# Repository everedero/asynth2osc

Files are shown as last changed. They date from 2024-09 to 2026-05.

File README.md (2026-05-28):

# Analog synthesizer to Open Sound Control (OSC) module

## Project description

Analog synth is coming back into hype among music artists. It has a strong culture of vintage, DIY, and customisation.

On the other hand, pro systems use digical control systems, such as DMX for lighting, or OpenSoundControl (OSC) for sound.

The idea for this project is to have a hardware to interface analog synth to advanced sound control systems.

This project is also designed to leverage the possibilities of open-source show control software [Chataigne](https://benjamin.kuperberg.fr/chataigne/).

There are a lot of solution to control an analog modular synthesizer from a computer, mainly by MIDI interfaces.
But not so much options to do the opposite: control others FROM analog modulations.
The features and purpose are very close to existing [Befaco VCMC](https://www.befaco.org/vcmc-2/), but with TCP-IP for OSC instead of serial for MIDI - so we need to change the microcontroller.

Some inspiration for hardware can be found at open hardware synths from Mutable Instruments company.
In its [repository](https://github.com/pichenettes/eurorack) we can find the exact reference design,
typically for the [Yarns V3](https://pichenettes.github.io/mutable-instruments-documentation/modules/yarns/) MIDI digital interface.

## Glossary

### Musical Instrument Digital Interface (MIDI)
Communication protocol dedicated to music, used for communication between musical instruments and multimedia devices.
Usually it is implemented as a serial connection, with a 5-pins DIN connector.

### OpenSoundControl (OSC)
Open, message-based protocol for communication between multimedia devices. Intended to be a next-generation replacement for MIDI.
[OSC specification 1.0 (Stanford University)](https://opensoundcontrol.stanford.edu/spec-1_0.html)
It is usually implemented on TCP-IP stack, most usually as UDP datagrams for real time applications.
It can be easily transmit thru Ethernet or Wifi at higher bit rate, and a much higher resolution of 32 bits float, than MIDI wich was based on 7 bits integer.

### CV - Control Voltages
The analog signals generated by the synthetisers are called CV.

### Gate and triggers
Other types of signals generated can be:
* Gate: a "digital" 0 and 1 signal, but with the synthesiser reference analog voltage,
* Trigger: a short-pulse "digital" 0 and 1 signal, to trigger a particular event.

### Chataigne
Chataigne is a user-friendly open-source show control software, allowing to connect several multimedia devices, hardware or software between them.
We develop belongside this hardware project asynth2osc a custom module for Chataigne, so this piece of software can be use easily to control anything from a real world analog modular,
from sound to light, videos and activators of any kind.

[Chataigne source code on Github](https://github.com/benkuper/Chataigne)
[Artist-friendly Modular Machine for Art and Technology - Chataigne Official website](http://benjamin.kuperberg.fr/chataigne)

### Analog synthetizer
Synthetizer that uses analog circuits and signals to generate sound electronically.
[See the wikipedia page](https://en.wikipedia.org/wiki/Analog_synthesizer)

### Analog modular synthetizer
Modular synthesizers are composed of separate hardware modules for different functions.
The modules can be connected together by the user to create a patch.
The outputs from the modules may include audio signals, analog control voltages, or digital signals for logic or timing conditions.
[See the wikipedia page](https://en.wikipedia.org/wiki/Modular_synthesizer)

### VCV Rack
Open-source software that emulate analog modular synthetizers. Most of hardware modules are present.
Especially, Tramasoft edited a module that is a kind of emulation of our asynth2osc module : cvOSCcv.
This virtual module can be use to use real world analog hardware to control the software.
[VCV Rack cvOSCcv module page](https://library.vcvrack.com/trowaSoft/cvOSCcv)

### Eurorack
Standardized mechanical format for synthetizer, in a modular 3U rack.
It usually fits in a "case" to ease musicians to build their own synthetizer, and have a unique Power Supply Unit and power busses for all the modules.

The dimensions are normalised :
* 3U = 128.5 mm height (U is professionnal standard 19" wide rack unit)
* 1HP = 5.08 mm, width is multiple of 1HP
* Depth should be <2.5mm or <4mm to be shallow

Exemple: Yarns is 12 HP and 3U, so front plate is 128.5x60.96mm. Its bottom PCB is tinier: 59x106,8mm, and has 3 screw holes to fit it to the front plate.

It uses 3.5mm jack for cabling, +/- 12V power supply on a 2x5p header connector, on the right lower corner of the board (facing the bottom).
Red side = -12V. Print a | on the board to indicate side. Don’t forget the protection circuit.

<!--
        +---------+
        |         |
 +12V   |  o   o  |  +12V
        |         |
 GND    |  o   o  |   GND
        |         |
 GND    |  o   o  |   GND
        |         |
 GND    |  o   o  |   GND
        |         |              |
 -12V   |  o   o  |  -12V        |
        |         |              |
        +---------+              |
                                 |
            ----                 |
                                 |
---------------------------------+
-->
Kroki generated Ditaa

## Benchmark
### Befaco VCMC specs (close features, MIDI only)
* Teensy 32 controller
    * NXP MK20DX256VLH7
    * 2x 16-bit ADC
    * 1x 12-bit DAC

* 8 CV muxed on 1 ADC

### Yarns V3 specs (close MCU, MIDI only)
* ST STM32F103CBT6 controller
    * 2x 12-bit ADC (16 channels)
    * 2x DAC
* External DAC DAC8564
    * 1x 16-bit DAC (4 channels)

## First architecture (RPI for Wifi, Bluetooth and cabled Ethernet support)
The first prototype includes:
* 8 analog inputs
* Rotary encoder and screen
* 4 digital inputs and 4 buttons for 8 interrupt inputs
* 1 analog audio output
* Pretty front panel with Eurorack format
* 5V power supply input

The BOM is:
* Raspberry Pi 3
* Pi-Plates DAQC2
* Adafruit I2C rotary encoder module, with click and LED #4991
* Adafruit quad-alphanumeric segmented display with I2C #1912
* 4 mini-arcade buttons with retro-lighting

### Pi-Plates DAQC2
This RPI hat is the GPIO interface, with a very good analog front end:
* Specs [here](https://pi-plates.com/daqc2r1/)

* SoC: Microchip PIC16F1517-I/PT
* 16x 10-bit ADC
* Analog input via TI SN74LV4051A 8:1 analog multiplexer
* Open Collector outputs via TI DS2003CM high-current Darlington driver and NXP 74HC 8-bit parallel-in/serial out shift register.

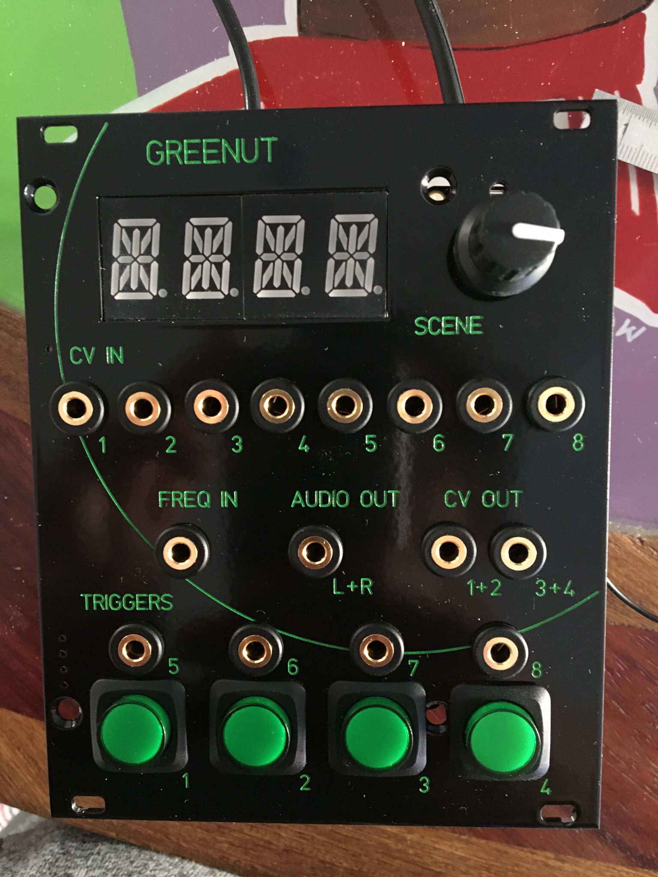
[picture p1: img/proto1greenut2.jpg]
proto1 front panel assembled

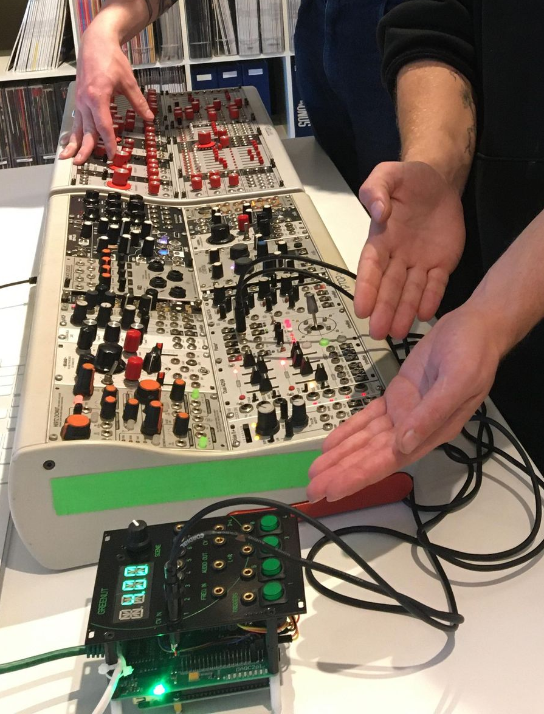
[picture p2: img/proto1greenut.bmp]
proto1 beta tests

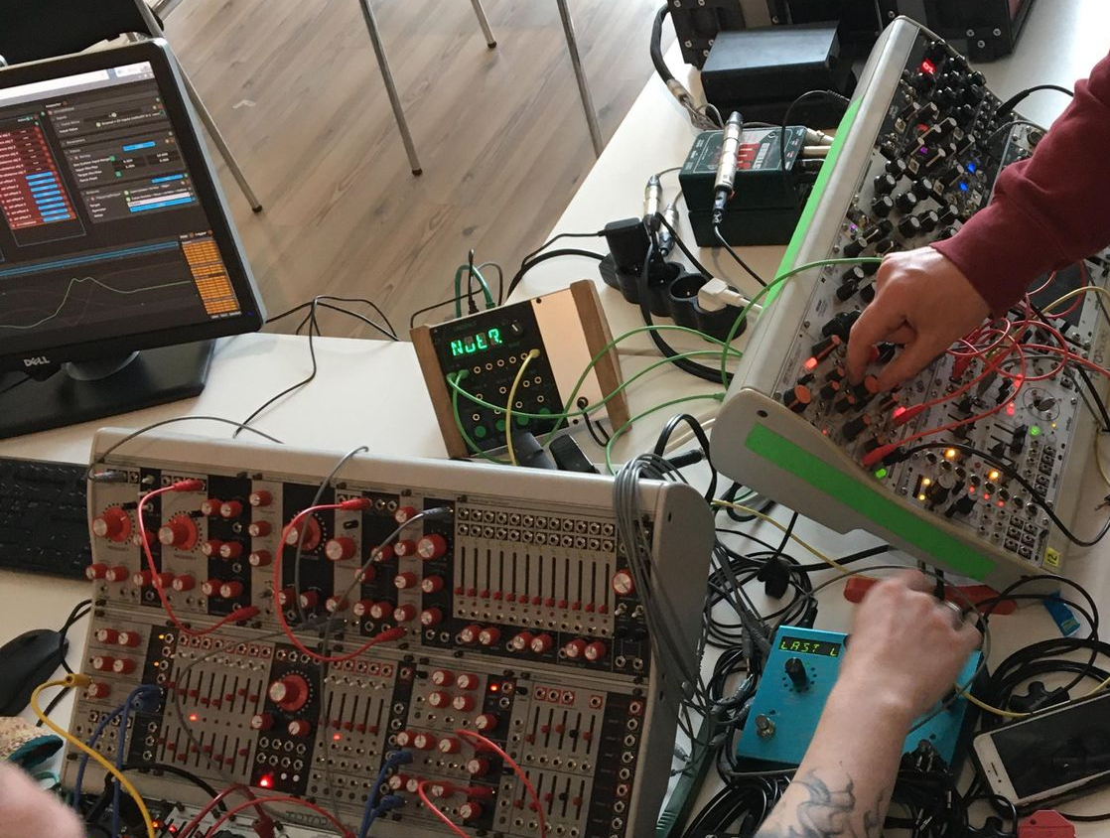
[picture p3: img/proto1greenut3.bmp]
proto1 beta tests


## Second architecture
This aims to integrate LEDs, buttons, and DACs on the same board to improve manufacturing and ralaibilty.
The Raspberry Pi is dropped and replaced by a custom board with WiFi/TCP-IP SoC and all the analog stuff.

It is possible to use a PCB board as front panel too, as a lot of synthesizer modules do.

For the software part, the board would only output the OSC.
I would consider implementing [TinyOSC](https://github.com/mhroth/tinyosc), a lightweight OSC implementation, preferably on Zephyr RTOS.

### Requirements
#### Ethernet
* Full TCP-IP stack implemented, with OSC other UDP protocol.
* DHCP, Link Local and Static IP settings.
* Wired RJ45, optionnal Wifi.

#### DAC
* This has to be the most crucial part for latency. Quick interface is preferable, like SPI.
* 8 channels input (audio stereo 3.5mm mini-jack).
* Minimum 16 bits, preferably 24.
* Sample rate: ideally at least 100Hz, application can be quite slow (LFO are around 2 Hz). Oversamplig is a must for smoothing and lower transmission rate.
* MCP3008 is an option.

#### Other IO
* MIDI input (also using stereo mini-jack).
Even if a lot of MIDI interface exist, and possibilties to send them other Ethernet with rtp-MIDI interfaces and protocol, forwarding some MIDI events to OSC would be a good feature.
With options to set the kind of datas (Programm Changes, Note ON, Control Changes etc) to be tranmitted.

MIDI in uses an UART port, see the [Arduino tutorial](https://www.instructables.com/Send-and-Receive-MIDI-with-Arduino/), or Yarns hardware.
Midi-jack pinout:

<!--
          | |
          +-+
NC 3  o           o  1  NC

Tip 5   o       o  4 Ring

            o
            2 Sleeve

          | |
          +-+
NC 3  o           o  1  NC

OUT- 5  o       o  4 OUT+

            o
            2 GND/Shield
-->
Kroki generated Ditaa

UART baud rate is 31250 kbps.

This is typa A MIDI on TRS, as explain in MIDI Standard : [https://midi.org/specification-for-use-of-trs-connectors-with-midi-devices](https://midi.org/specification-for-use-of-trs-connectors-with-midi-devices)
Warning : There is a type B standard also in use, see [https://minimidi.world/](https://minimidi.world/)

#### Power supply
Eurorack standard includes a +12/-12V power supply, but the currents are quite low, and sensitive to pollution. So we should rather use a 5V additional external power supply as an option.

#### Mechanical
It has to fit in Eurorack format. The smaller, the better,but no hard requirement for width.
Some work has to be done to fit the connectors, leds, buttons and mechanical parts nicely.

#### CV inputs

VC analog inputs can wiggle between several voltage ranges:
* -5V / 5V
* -12V / 12V
* 0 / 5V
* 0 / 12V

We need an input stage able to fit those input the 0 / 3.3V ADC microcontroller input.

Attenuators are specific modules used to reshape a specific CV.

The most used input is copied from Mutable Instruments and remaps a -5V / 5V input in a 0 / 3.3V output, but needs a -10V bias to handle those negatives.
In Befaco VCMC, an optional voltage gizmo converts 5V power supply to -12V / +12V for standalone behaviour.
We could also use an inverting circuit but it will... invert: -5V mapped to 3.3V and 5V mapped to 0V.

Voltages are clamped to 0-3.3V using Shottky diodes, but it should maybe signal saturation to the user somehow.

Better scaling:
* Several input scalers muxed?
* A fancy IC with digital control?
* Single scaler controlled by DAC output (hard)?
* 2-steps converter: rescaler (-12/12 to -5/5), scaler (-5/5 to 0/3).

#### Diagram
<!--
graph TD
  A[ ESP32 ] ==>| RMII | B[ Ethernet PHY ]
  A <==> | SPI | C[ NOR Flash ]
  A <==> | I2C | D[ GPIO expander ]
  T> MIDI in] ==> D
  D ==> | GPIO | E> LEDs ]
  F> Buttons ] ==> | GPIO | D
  G[ ADC ] ==> | SPI | A
  H[ Analog magic ] ==> | Analog | G
  I> 3.5 jacks ] ==> H
  B ==> J> RJ45 ]
  A ==> | DAC | M[ Analog out ]
  M ==> N> 3.5 jack ]
  M ==> O> PWM LED ]
  K> Power jack ] -.- | 12V | L[ DCDC ]
  L -.- | 3V3 | A
  A <==> | UART, JTAG | P[ FTDI ]
  P ==> Q> Debug USB ]
  Q -.- | 5V | L
  A === | U.FL | R[ Antenna ]
  A ==> | SPI | S> Display ]
-->

Kroki generated Mermaid

#### STM32 option
* Only performance range (STM32F7 and STM32H7) have RMII
* STM32H7 has 16-bits ADC, it's perfect

<!--
graph TD
  A[ STM32 ] ==>| RMII | B[ Ethernet PHY ]
  A <==> | SPI | C[ NOR Flash ]
  A <==> | GPIO | D> LEDs ]
  E> Buttons ] ==> | GPIO | A
  H[ Analog in ] ==> | ADC | A
  I> 3.5 jacks ] ==> H
  B ==> J> RJ45 ]
  A ==> | DAC | F[ Analog out ]
  F ==> N> 3.5 jack ]
  A ==> | PWM | O> PWM LED ]
  K> Power jack ] -.- | 12V | L[ DCDC ]
  L -.- | 3V3 | A
  A <==> | UART, JTAG | P> SWD header ]
  L -.- | 5V | G
  A ==> | SPI | S> Display ]
  T> 3.5 jack ] ==> U[ MIDI In ]
  U ==> | GPIO | A
  A <==> | USB | G> Debug USB ]
-->
Kroki generated Mermaid

# Power consumptions estimates
## 3V3 bus
* STM32H7 absolute maximum current through VDD/VSS: 620mA
* STM32H7 running at 100deg, VOS1, all peripheral enabled: around 500mA
* ETH PHY, 10BASE-T traffic: 130mA
* OLED display logic: 300uA

* 3V3 LDO: 800 mA
* Fuse: 1.25A, trip 2.5A
* Filter ferrite rating: 3A
* Schottky rating (SS24): 2A

## 10V
* OLED display lighting: 25mA
* Step-up rating: 2.1A
* Step-up inductor: 2.4A
* Schottky rating (SS24): 2A

## 12V
* Schottky rating (1N5819W): 1A
* LDO efficiency (vout/vin): 12-5V -> 42%, 5-3V -> 66%
* 800mA @ 3V3 => 800mA @ 12V (not crazy, but linear)

## 5V
* USB spec: 500 mA in USB 2.0
* USB spec: 900 mA in USB 3.0
* USB 2.0: 500mA on 3V3 after LDO
* USB 3.0: 900mA on 3V3 after LDO
Might be useful to have USB 3.0 supply.

# Notes about JLCPCB files
## Generate files

Some modification are required from Kicad output files (BOM csv and placement files) to be imported to JLCPCB for assembly.

* Change field names in BOM and placement CSV headers
* Fix component rotation

There is a way to automate both with a Python script called [jlc-kicad-tools](https://github.com/matthewlai/JLCKicadTools/tree/master).

This script uses a rotation look-up-table called cpl\_rotations\_db.csv. Update this file with the one in this repository.

    cp [PRJ]/kicad/tools/cpl_rotations_db.csv [INSTALLFOLDER]/JLCKicadTools/jlc_kicad_tools

Then install your version from the local folder:

    pip3 install [INSTALLFOLDER]/JLCKicadTools

You will need 2 files in the project folder:

* Netlist file: project.xml
* Placement file: project-all-pos.csv

In order to get the project.xml file, in Eeschema, go to "Legacy BOM", create a custom XML exporter with the following command:
```
/bin/echo "%I"
```

Don’t forget to create a "JLCPCB" column with the JLCPCB references, for advanced components. For standard ones, keep their value and package and use the "--include-all-component-groups", otherwise the script will erase them.

Exemple use:
```
jlc-kicad-tools myproject -o ./assembly --include-all-component-groups
```

## Pricing

Here is an approximate price breakdown for manufacturing at JLCPCB.
Some components, such as though-hole or big components, will be ordered separately on LCSC and soldered by hand.
The "component" line includes both PCBa and by-hand BOMs.
Here, we manufacture 5 boards.

| Item | Price |
|---|---|
| Components | 151€  |
| PCB manufacturing | 28€ |
| PCB assembly | 105€  |
| Shipping | 35€ |
| Refunds | 18€ |
| Total (x5 boards) | 300€  |

This is a total of 60€ / board.

# Bringup
## V0.1 known issues
* PHY: Error in LDO routing: VDDCR pin 6 is an internally regulated LDO 1.2V output, not to be connected to 3V3 supply.
Add 1 μF and 470 pF decoupling capacitors to ground.
* PHY: nINTSEL should be 0, change LED2 connection to pull-down.
    * REF_CLK_OUT is used to generate the 50MHz clock for RMII
    * This special feature allows to use a 25 MHz crystal with the LAN8742
    * As a consequence, the INT/CLKO pin must be set to clock out, not int
    * This means nINTSEL/LED2 pulled down
* Cannot setup different interrupts for GPIO (EXTI register) having the same numbers but on different ports.
    * See [this issue](https://github.com/zephyrproject-rtos/zephyr/issues/45234).
    * Issue with A8 rotative encoder pushbutton VS C8 rotary input B
    * Issue with D14 rotary input A and E14 trig input
* Shield REFCLK0: it is a 50MHz line!
* Missing pin 1 dot on diode D2 for manufacturing
* Dot around ethernet PHY: crystal dot too close
* Put poka-yoke or marking to mount USB connector on right side
* Put poka-yoke or marking for buttons
* Reduce jack connectors holes to mount more precisely
* Add testpoints for MDIO?
* Maybe disconnect PHY reset from main reset
Reset is pulled low by STLink probe, it has 1V2 value when probe is connected even if not plugged in.

## Bringup todo list
* Debug LEDs: OK
* Buttons: OK
* Buttons LEDs: OK, make markings for equipment
* UART2: OK
* Enable 10V: OK
* USB data: OK, make markings for equipment
* QSPI flash: OK
* MDIO bus / RMII / Ethernet: OK after rework, ldo disconnect and led2 pull-down
* Display: OK, verify grey lines, maybe voltage bias issue
* DAC: TBD
* Analog: OK, CVin ripple at +max value (+5V or +12V)
* Trigger: OK, 1.95ms rise time (max 500 Hz trig)
* MIDI optocoupler: OK at 32kHz, bit of an hysteresis at play. Collapses after 150kHz.
* MIDI: OK, tested with Roland HP201 keyboard output
* Supply (12V alternative input, current consumption measurements): TBD
  * 12V input: 5V LDO works, 214mA consumption with ADC app running, no display
  * 5V input: 208mA consumption with ADC app running, no display
  * 5V filtered output is around 4.5V

## Meca panel known issues
* First CNC run:
  * Rotary hole exact diameter, add a small margin
  * Button hole too small, about 1mm missing, add margin too
  * Jack holes too wide, wiggling
  * Display TBD, might be too small or not

* Reverse-mount LED options:
  * XZDGK45WT-9 (Green)
  * XZCWD45S-9 (White)
  * XZFBB45S-9 (Blue)
  * XZMDK45WT-9 (Red)

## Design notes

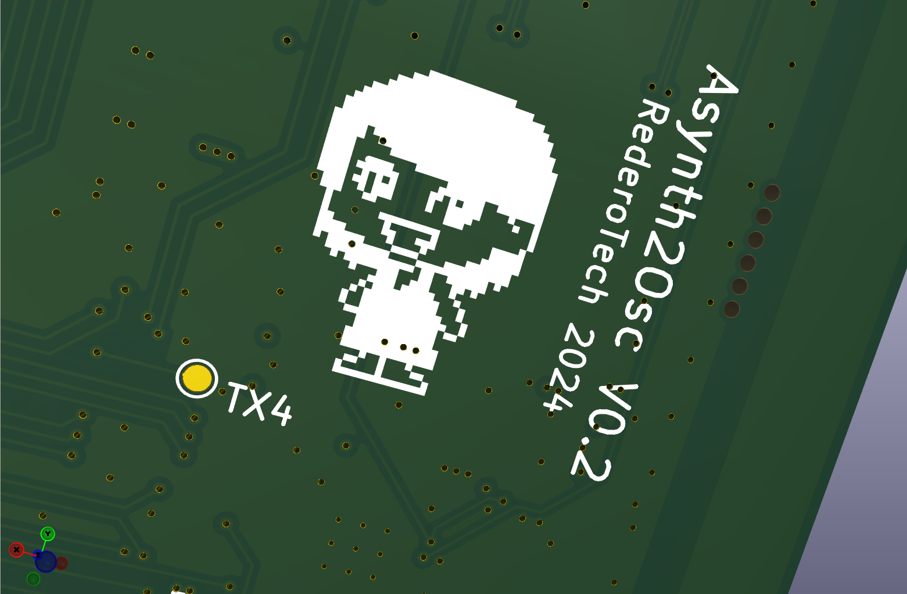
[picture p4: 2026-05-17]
docs/images/RederoTech2024.png

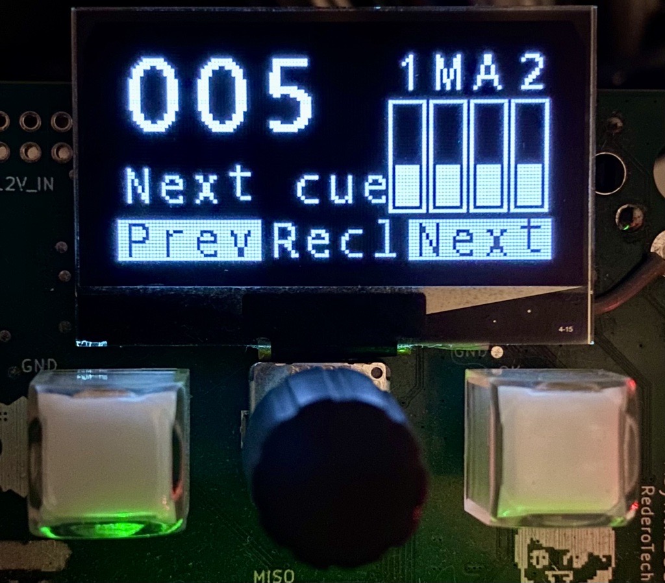
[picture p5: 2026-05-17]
docs/images/oled_ASynthOSC.jpg

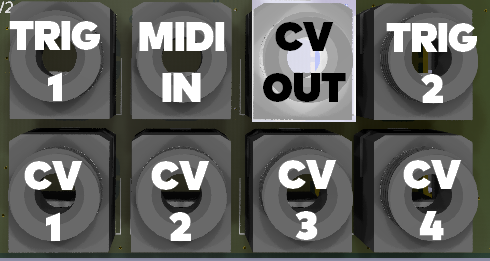
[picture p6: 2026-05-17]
docs/images/jacks_ASynthOSC.png

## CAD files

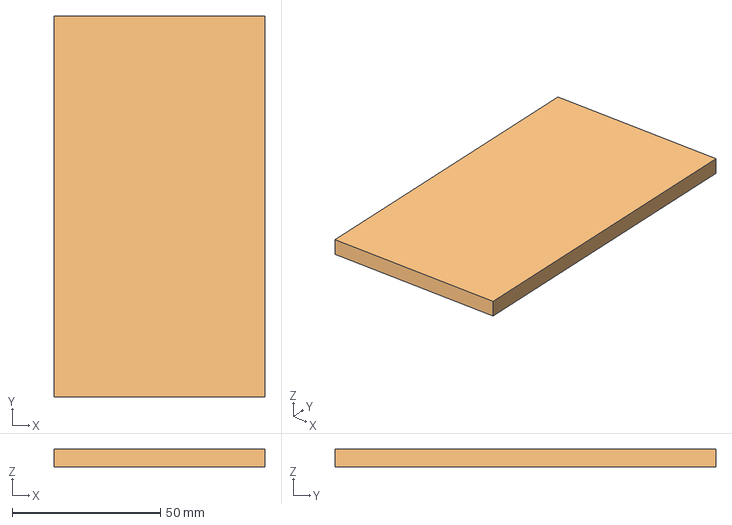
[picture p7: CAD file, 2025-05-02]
freecad/panel_sketch.FCStd
71.1 x 128.4 x 6.00 mm
Model-Body
Stock

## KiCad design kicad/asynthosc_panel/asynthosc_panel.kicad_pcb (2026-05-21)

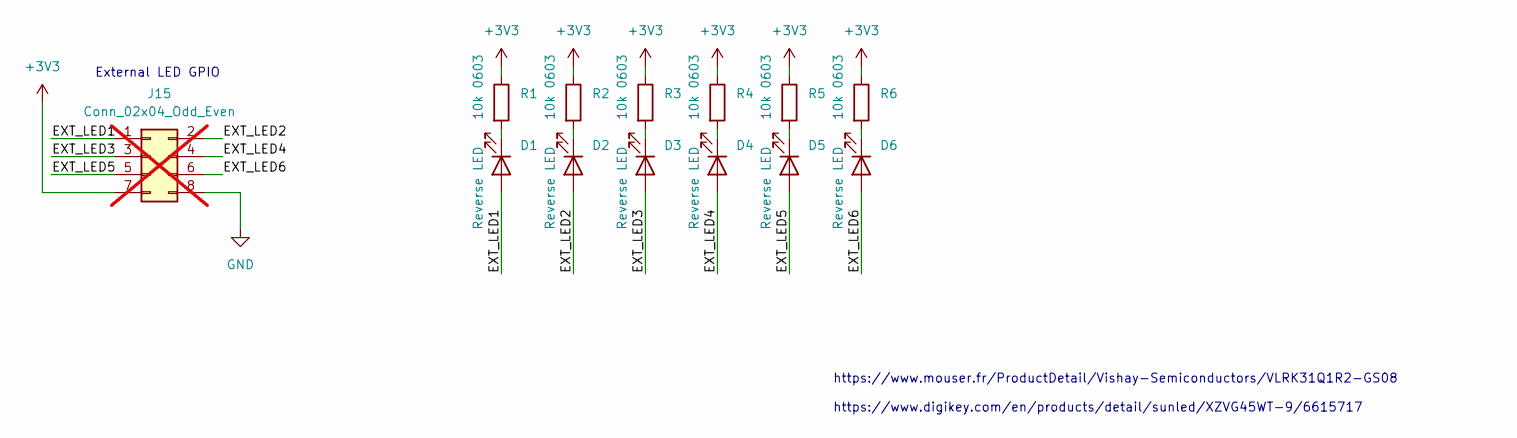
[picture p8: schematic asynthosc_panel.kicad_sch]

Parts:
D1, D2, D3, D4, D5, D6: Reverse LED; LED_Sunled_XZxx45x-9_nohole
J15: Conn_02x04_Odd_Even; PinHeader_2x04_P2.54mm_Vertical_SMD; LCSC C192300; not fitted
R1, R2, R3, R4, R5, R6: 10k 0603; R_0603_1608Metric_Pad0.98x0.95mm_HandSolder

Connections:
+3V3: J15.7, R1.1, R2.1, R3.1, R4.1, R5.1, R6.1
/EXT_LED1: D1.2 (A), J15.1
/EXT_LED2: D2.2 (A), J15.2
/EXT_LED3: D3.2 (A), J15.3
/EXT_LED4: D4.2 (A), J15.4
/EXT_LED5: D5.2 (A), J15.5
/EXT_LED6: D6.2 (A), J15.6
GND: J15.8
unnamed: D1.1 (K), R1.2
unnamed: D2.1 (K), R2.2
unnamed: D3.1 (K), R3.2
unnamed: D4.1 (K), R4.2
unnamed: D5.1 (K), R5.2
unnamed: D6.1 (K), R6.2

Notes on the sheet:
https://www.mouser.fr/ProductDetail/Vishay-Semiconductors/VLRK31Q1R2-GS08 https://www.digikey.com/en/products/detail/sunled/XZVG45WT-9/6615717
External LED GPIO

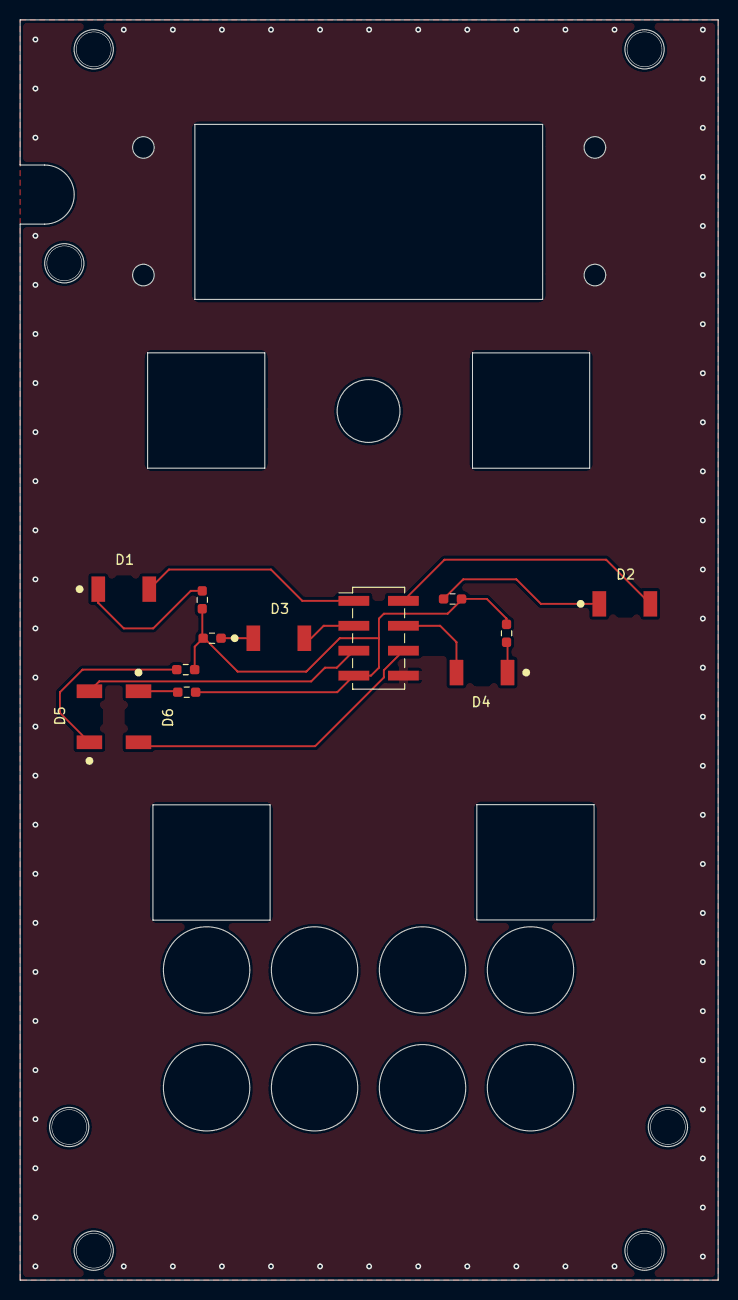
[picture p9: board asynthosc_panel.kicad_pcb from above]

Board: 2 copper layers, 71.1 x 128.4 mm, 13 parts (0 on the bottom side), 13 nets.

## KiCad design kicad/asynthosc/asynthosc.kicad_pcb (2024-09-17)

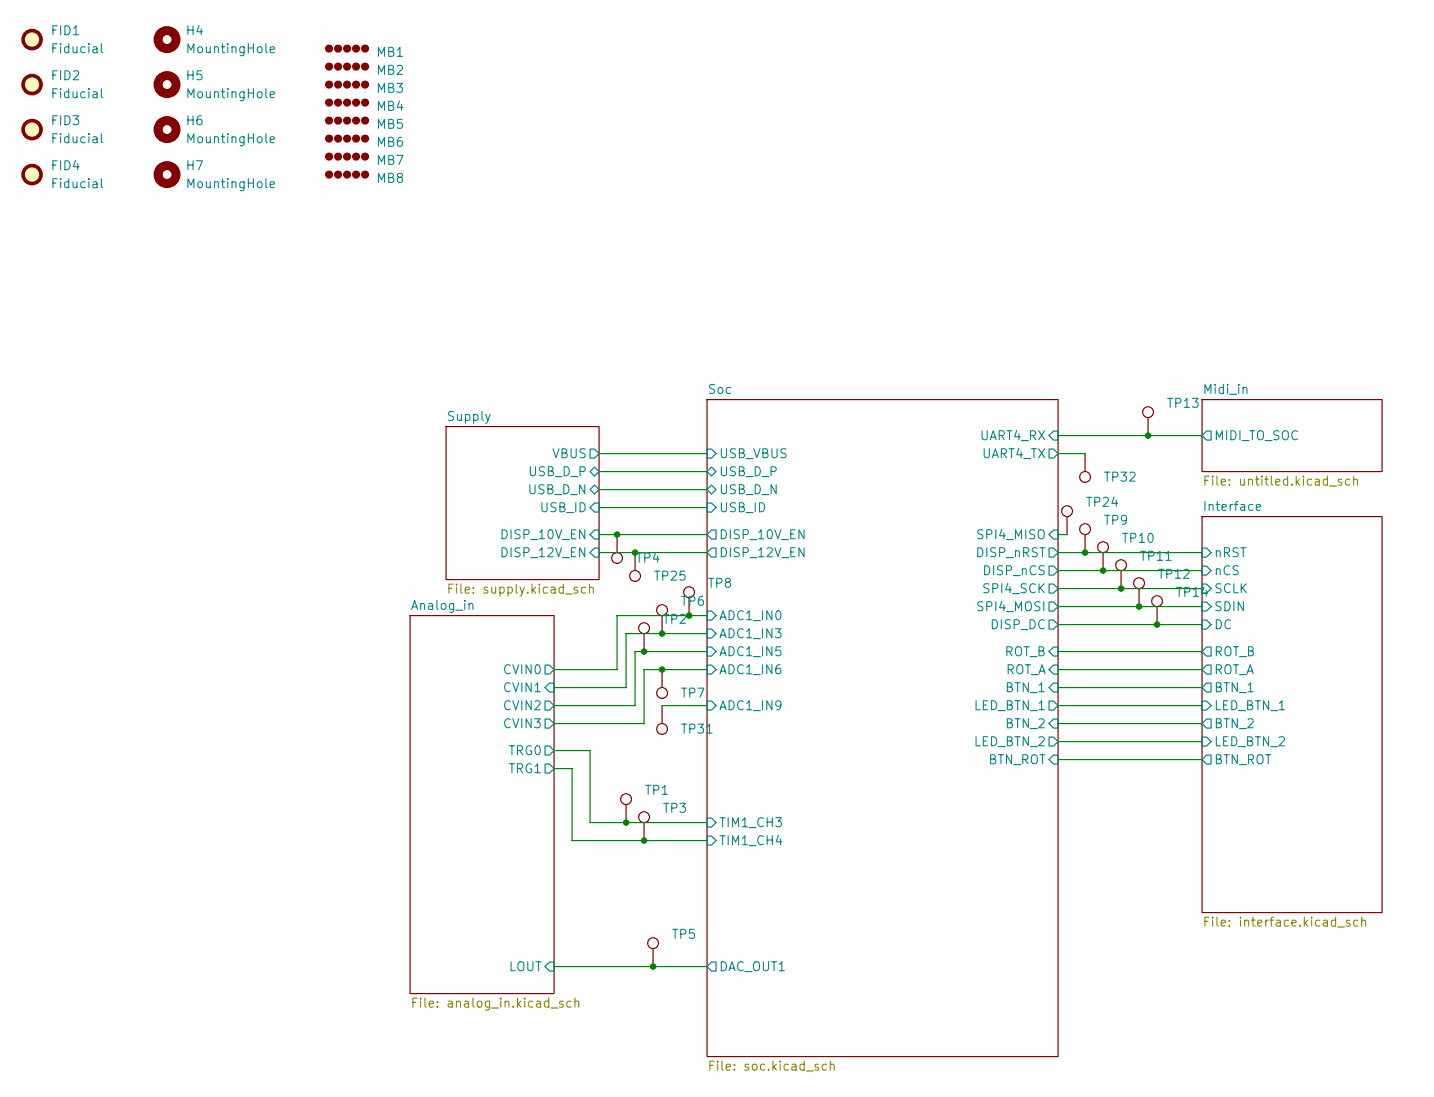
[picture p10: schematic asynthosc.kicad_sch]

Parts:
FID1, FID2, FID3, FID4: Fiducial; Fiducial_1mm_Mask2mm
H4, H5, H6, H7: MountingHole; MountingHole_JLC_3.5mm
MB1, MB2, MB3, MB4, MB5, MB6, MB7, MB8: MouseBytes; MouseBytes_JLC
TP1, TP2, TP3, TP4, TP5, TP6, TP7, TP8, TP9, TP10, TP11, TP12, TP13, TP14, TP24, TP25, TP31, TP32: TestPoint; TestPoint_Pad_D1.0mm

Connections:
/Analog_in/CVIN0: TP8.1; also elsewhere on the board
/Analog_in/CVIN1: TP6.1; also elsewhere on the board
/Analog_in/CVIN2: TP2.1; also elsewhere on the board
/Analog_in/CVIN3: TP7.1; also elsewhere on the board
/Analog_in/TRG0: TP1.1; also elsewhere on the board
/Analog_in/TRG1: TP3.1; also elsewhere on the board
/Interface/DC: TP14.1; also elsewhere on the board
/Interface/SDIN: TP12.1; also elsewhere on the board
/Interface/nCS: TP10.1; also elsewhere on the board
/Interface/nRST: TP9.1; also elsewhere on the board
/Midi_in/MIDI_TO_SOC: TP13.1; also elsewhere on the board
/Soc/ADC1_IN9: TP31.1; also elsewhere on the board
/Soc/DAC_OUT1: TP5.1; also elsewhere on the board
/Soc/DISP_10V_EN: TP4.1; also elsewhere on the board
/Soc/DISP_12V_EN: TP25.1; also elsewhere on the board
/Soc/SPI4_MISO: TP24.1; also elsewhere on the board
/Soc/SPI4_SCK: TP11.1; also elsewhere on the board
/Soc/UART4_TX: TP32.1; also elsewhere on the board

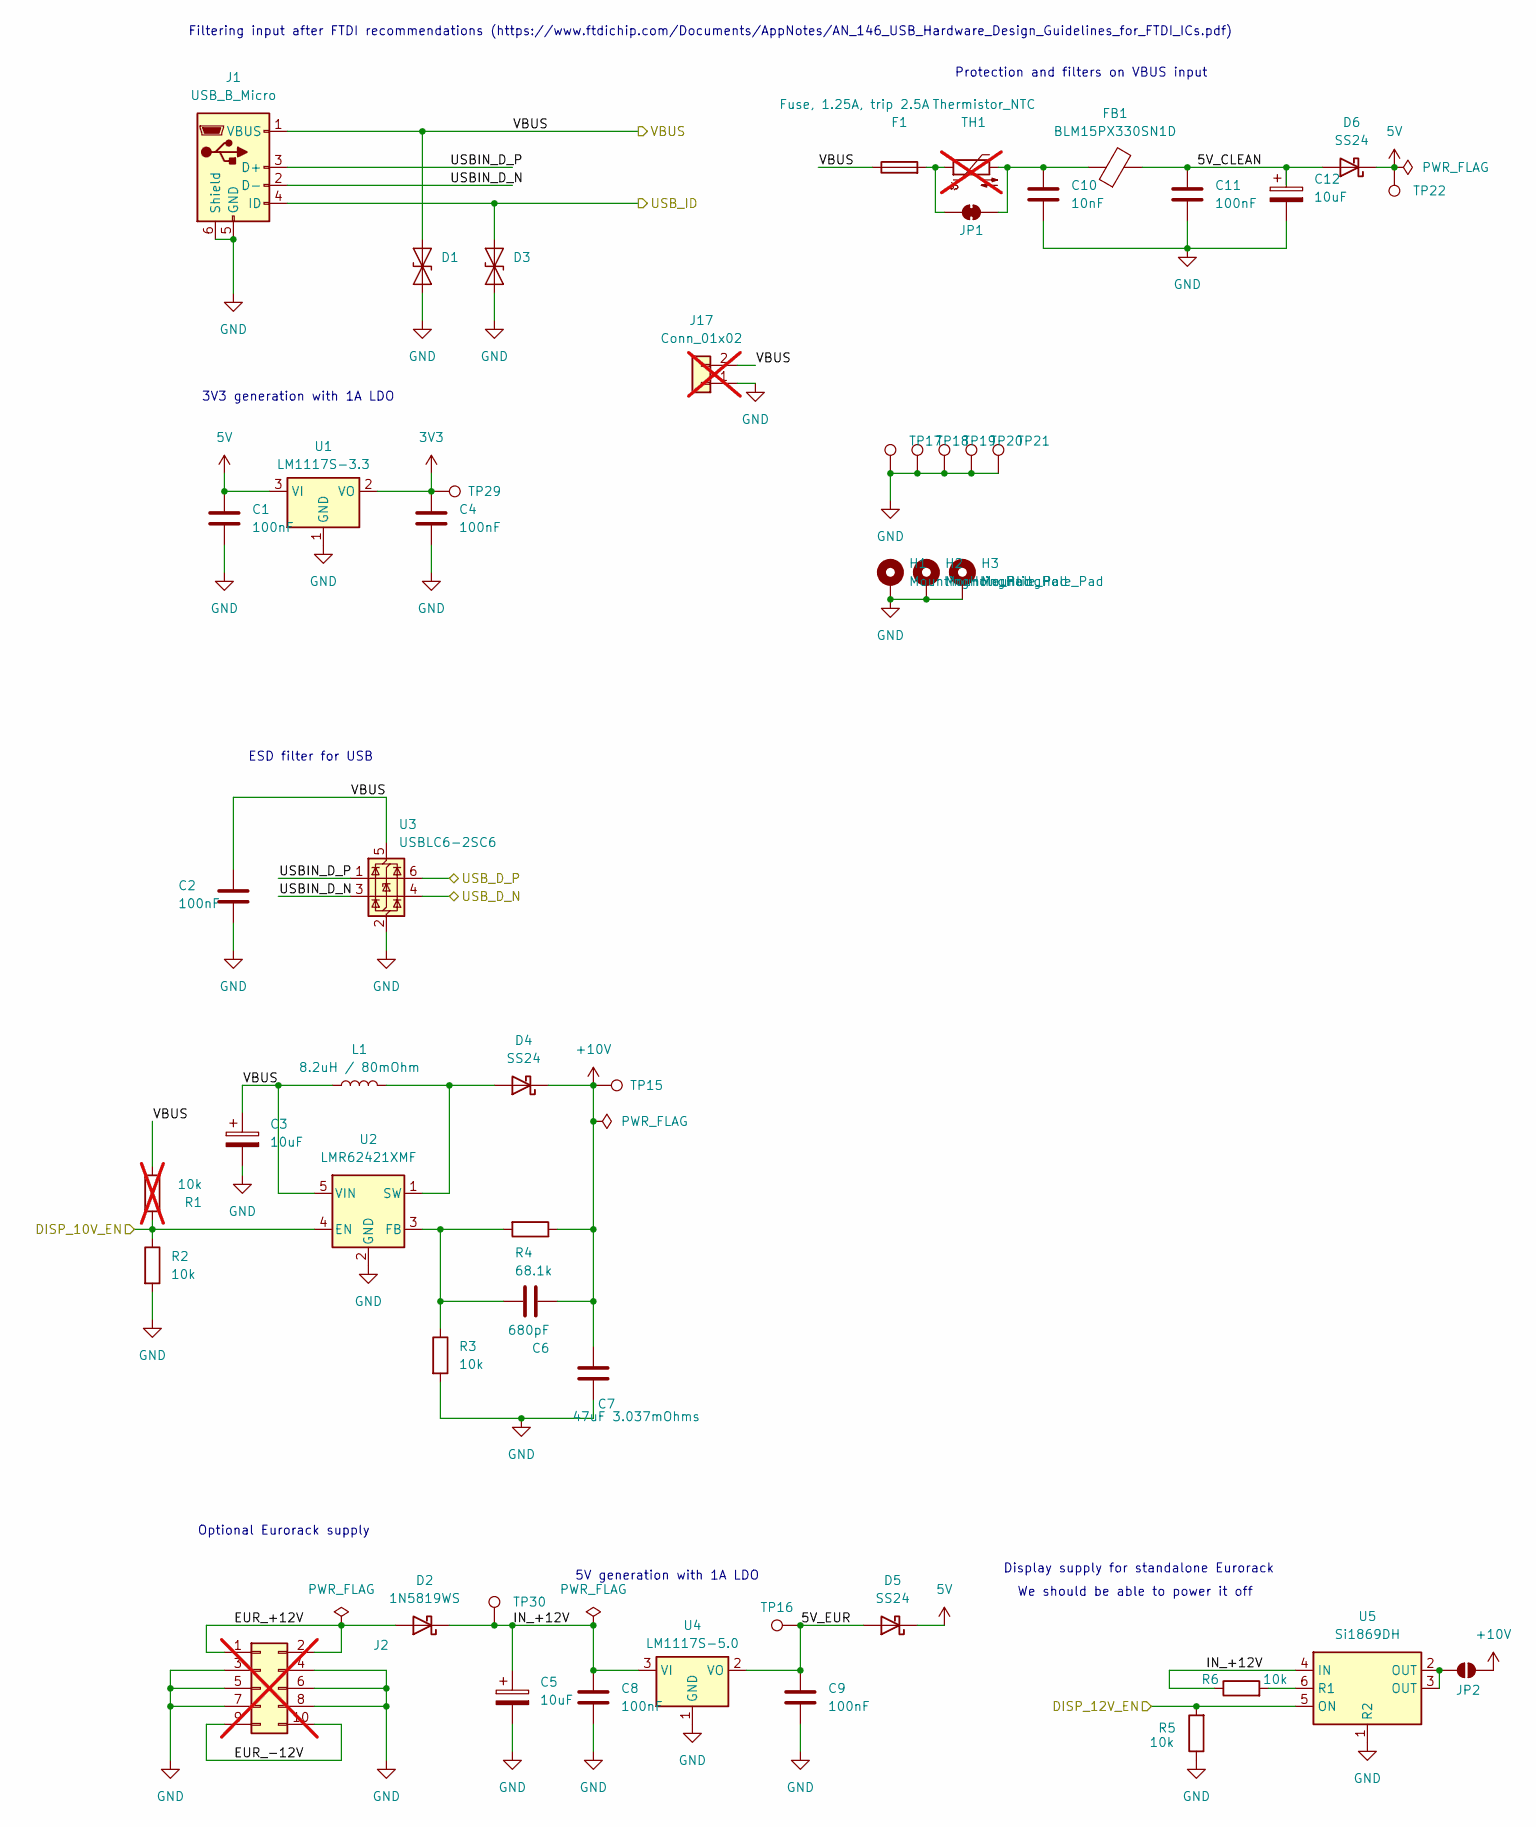
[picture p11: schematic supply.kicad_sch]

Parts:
C1, C2, C4, C8, C9: 100nF; C_0805_2012Metric; JLC 0805
C3, C5, C12: 10uF; CP_Elec_4x5.4; LCSC C72485
C6: 680pF; C_0402_1005Metric; JLC 0402
C7: 47uF 3.037mOhms; C_0805_2012Metric; JLC 0805
C10: 10nF; C_0402_1005Metric; JLC 0402
C11: 100nF; C_0402_1005Metric; JLC 0402
D1, D3: ESD9B5.0ST5G; D_SOD-923; LCSC C111566
D2: 1N5819WS; D_SOD-323; LCSC C2921026
D4, D5, D6: SS24; D_SMA; LCSC C3014007
F1: Fuse, 1.25A, trip 2.5A; R_0805_2012Metric; JLC 0805
FB1: BLM15PX330SN1D; L_0402_1005Metric; LCSC C160974
H1, H2, H3: MountingHole_Pad; MountingHole_2.2mm_M2_Pad
J1: USB_B_Micro; USB_Micro-B_Hanxia_HX_MICRO_180D_ZB; LCSC C5160321
J2: Conn_02x05_Odd_Even; PinHeader_2x05_P2.54mm_Vertical; LCSC C3294463; not fitted
J17: Conn_01x02; PinHeader_1x02_P2.54mm_Vertical; not fitted
JP1: SolderJumper_2_Bridged; SolderJumper_0402_1005Metric_Bridged
JP2: SolderJumper_2_Open; R_0402_1005Metric
L1: 8.2uH / 80mOhm; L_XR_XRCD75-XRX_7x7.8; LCSC C7462918
R1: 10k; R_0402_1005Metric; JLC 0402; not fitted
R2, R3, R5, R6: 10k; R_0402_1005Metric; JLC 0402
R4: 68.1k; R_0402_1005Metric; JLC 0402
TH1: Thermistor_NTC; R_Axial_DIN0204_L3.6mm_D1.6mm_P7.62mm_Horizontal; LCSC C2935581; not fitted
TP15, TP16, TP17, TP18, TP19, TP20, TP21, TP22, TP29, TP30: TestPoint; TestPoint_Pad_D1.0mm
U1: LM1117S-3.3; SOT-223; LCSC C126027
U2: LMR62421XMF; SOT-23-5; LCSC C2070685
U3: USBLC6-2SC6; SOT-23-6; LCSC C7519
U4: LM1117S-5.0; SOT-223; LCSC C126028
U5: Si1869DH; SOT-363_SC-70-6; LCSC C5246384

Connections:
3V3: C4.1, TP29.1, U1.2 (VO); also elsewhere on the board
5V: C1.1, D5.1 (K), D6.1 (K), TP22.1, U1.3 (VI); also elsewhere on the board
+10V: C6.2, C7.1, D4.1 (K), JP2.2 (B), R4.1, TP15.1; also elsewhere on the board
/Soc/DISP_10V_EN: R1.1, R2.1, U2.4 (EN); also elsewhere on the board
/Soc/DISP_12V_EN: R5.2, U5.5 (ON); also elsewhere on the board
/Soc/USB_D_N: U3.4 (I/O2); also elsewhere on the board
/Soc/USB_D_P: U3.6 (I/O1); also elsewhere on the board
/Soc/USB_ID: D3.2 (A2), J1.4 (ID); also elsewhere on the board
/Supply/5V_CLEAN: C11.1, C12.1, D6.2 (A), FB1.2
/Supply/5V_EUR: C9.1, D5.2 (A), TP16.1, U4.2 (VO)
/Supply/EUR_+12V: D2.2 (A), J2.1, J2.2
/Supply/EUR_-12V: J2.9, J2.10
/Supply/IN_+12V: C5.1, C8.1, D2.1 (K), R6.1, TP30.1, U4.3 (VI), U5.4 (IN)
/Supply/USBIN_D_N: J1.2 (D-), U3.3 (I/O2)
/Supply/USBIN_D_P: J1.3 (D+), U3.1 (I/O1)
/Supply/VBUS: C2.1, C3.1, D1.2 (A2), F1.1, J1.1 (VBUS), J17.2, L1.1, R1.2, U2.5 (VIN), U3.5 (VBUS); also elsewhere on the board
GND: C1.2, C2.2, C3.2, C4.2, C5.2, C7.2, C8.2, C9.2, C10.2, C11.2, C12.2, D1.1 (A1), D3.1 (A1), H1.1, H2.1, H3.1, J1.5 (GND), J1.6 (Shield), J2.3, J2.4, J2.5, J2.6, J2.7, J2.8, J17.1, R2.2, R3.2, R5.1, TP17.1, TP18.1, TP19.1, TP20.1, TP21.1, U1.1 (GND), U2.2 (GND), U3.2 (GND), U4.1 (GND), U5.1 (R2); also elsewhere on the board
unnamed: D4.2 (A), L1.2, U2.1 (SW)
unnamed: F1.2, JP1.1 (A), TH1.1
unnamed: C10.1, FB1.1, JP1.2 (B), TH1.2
unnamed: JP2.1 (A), U5.2 (OUT), U5.3 (OUT)
unnamed: C6.1, R3.1, R4.2, U2.3 (FB)
unnamed: R6.2, U5.6 (R1)

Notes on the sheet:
We should be able to power it off
Optional Eurorack supply
Filtering input after FTDI recommendations (https://www.ftdichip.com/Documents/AppNotes/AN_146_USB_Hardware_Design_Guidelines_for_FTDI_ICs.pdf)
Display supply for standalone Eurorack
ESD filter for USB
Protection and filters on VBUS input
5V generation with 1A LDO
3V3 generation with 1A LDO

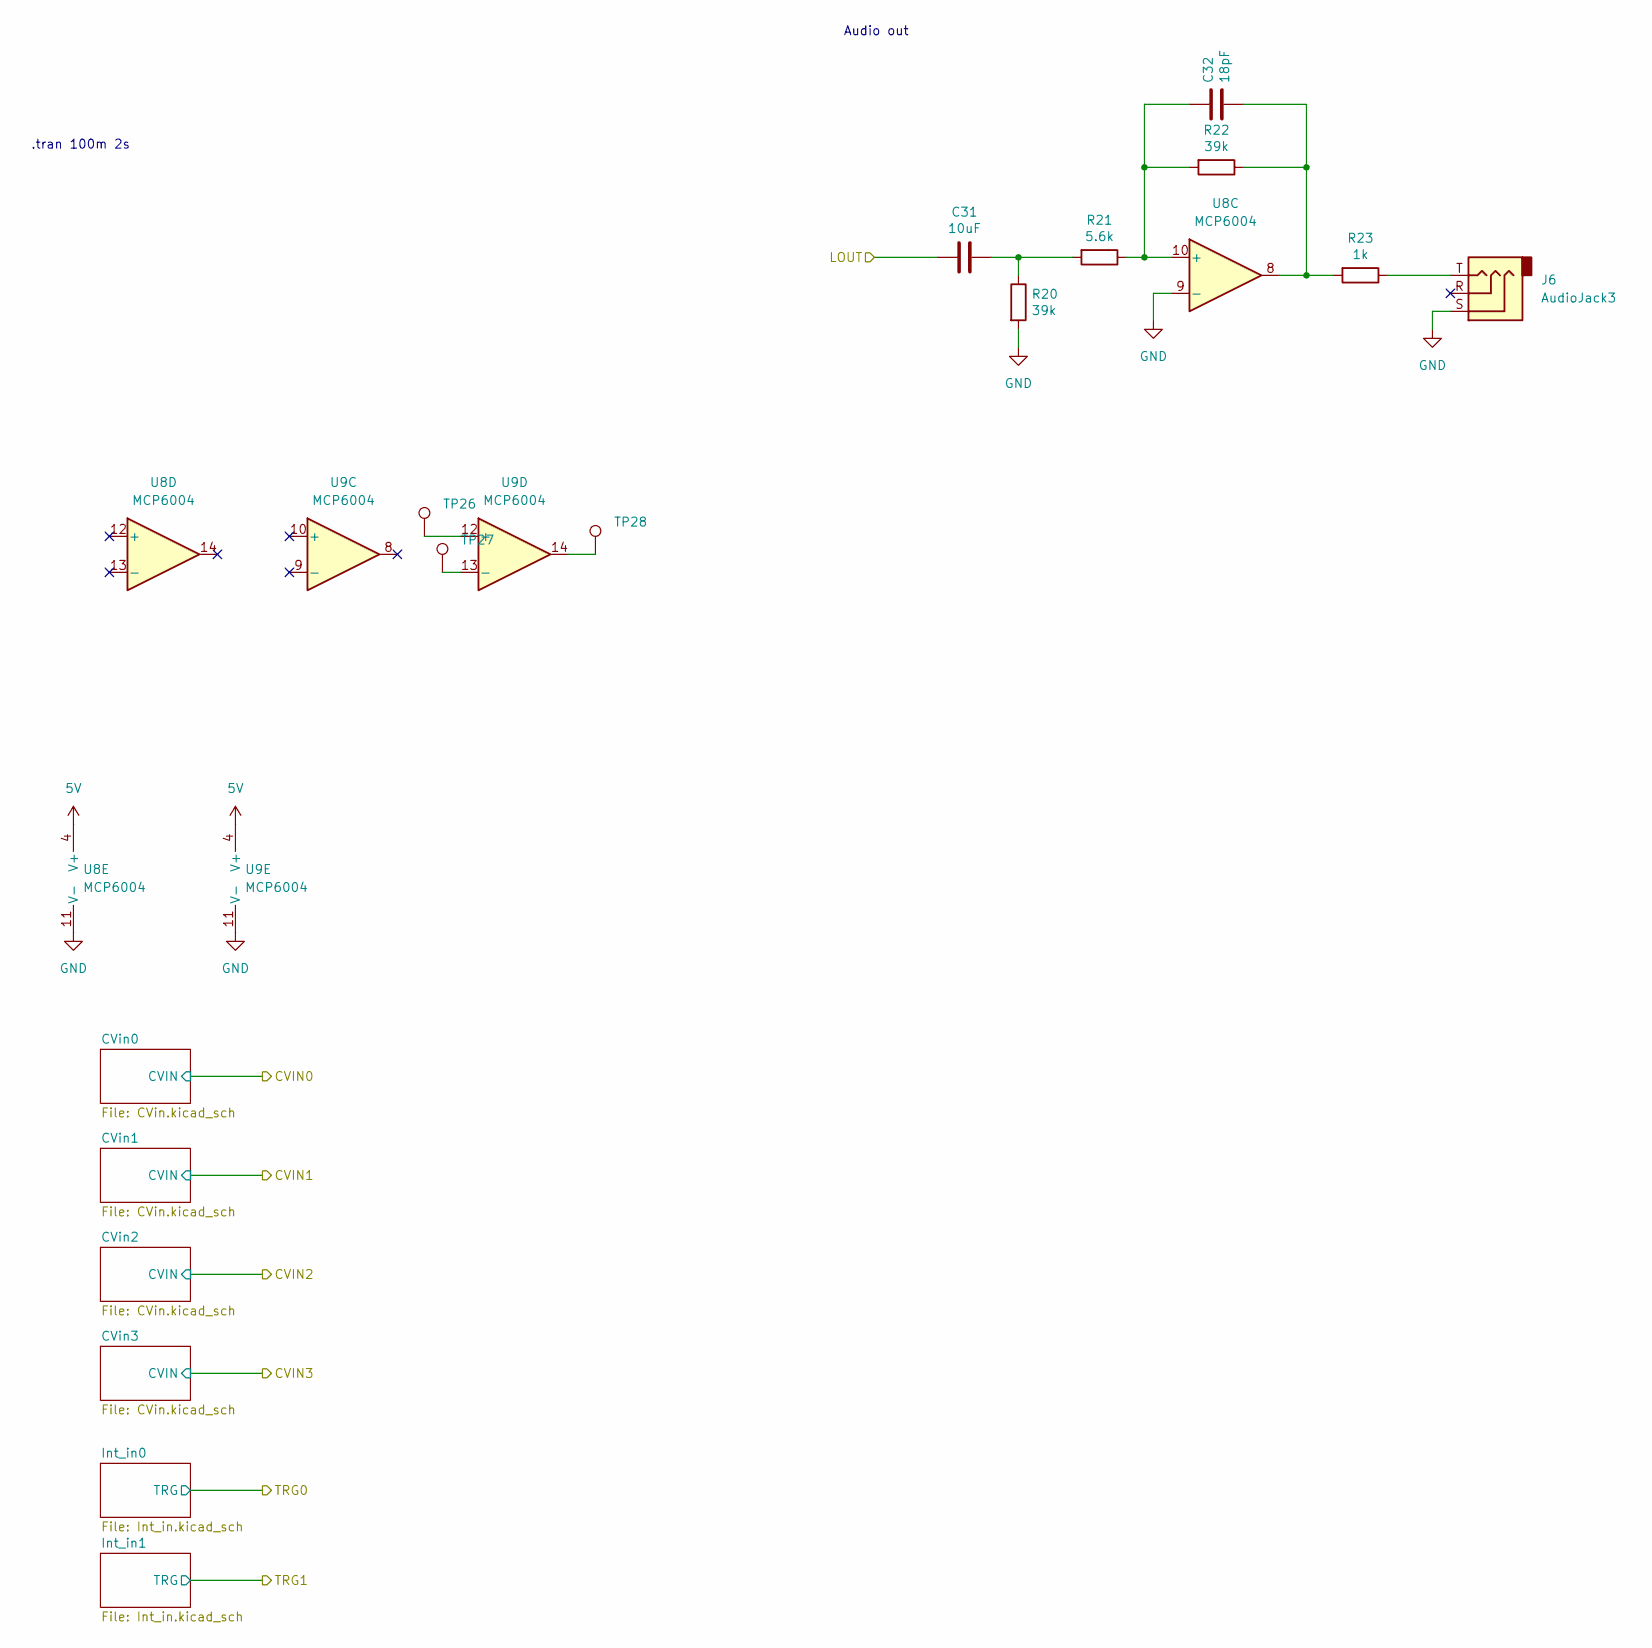
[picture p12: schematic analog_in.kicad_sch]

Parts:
C31: 10uF; C_0805_2012Metric; JLC 0805
C32: 18pF; C_0603_1608Metric; JLC 0603
J6: AudioJack3; Jack_3.5mm_3legs_XKB_PJ-3411_Vertical; LCSC C381132
R20, R22: 39k; R_0402_1005Metric; JLC 0402
R21: 5.6k; R_0402_1005Metric; JLC 0402
R23: 1k; R_0402_1005Metric; JLC 0402
TP26, TP27, TP28: TestPoint; TestPoint_Pad_D1.0mm
U8, U9: MCP6004; TSSOP-14_4.4x5mm_P0.65mm; LCSC C627416

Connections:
5V: U8.4 (V+), U9.4 (V+); also elsewhere on the board
/Analog_in/CVIN0: U8.1; also elsewhere on the board
/Analog_in/CVIN2: U9.1; also elsewhere on the board
/Soc/DAC_OUT1: C31.2; also elsewhere on the board
GND: J6.S, R20.2, U8.9 (-), U8.11 (V-), U9.11 (V-); also elsewhere on the board
unnamed: C31.1, R20.1, R21.2
unnamed: C32.2, R22.1, R23.2, U8.8
unnamed: J6.T, R23.1
unnamed: TP28.1, U9.14
unnamed 148: U8.3 (+); also elsewhere on the board
unnamed 149: U8.2 (-); also elsewhere on the board
unnamed: C32.1, R21.1, R22.2, U8.10 (+)
unnamed 153: U9.3 (+); also elsewhere on the board
unnamed 154: U9.2 (-); also elsewhere on the board
unnamed: TP26.1, U9.12 (+)
unnamed: TP27.1, U9.13 (-)

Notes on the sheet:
Audio out
.tran 100m 2s

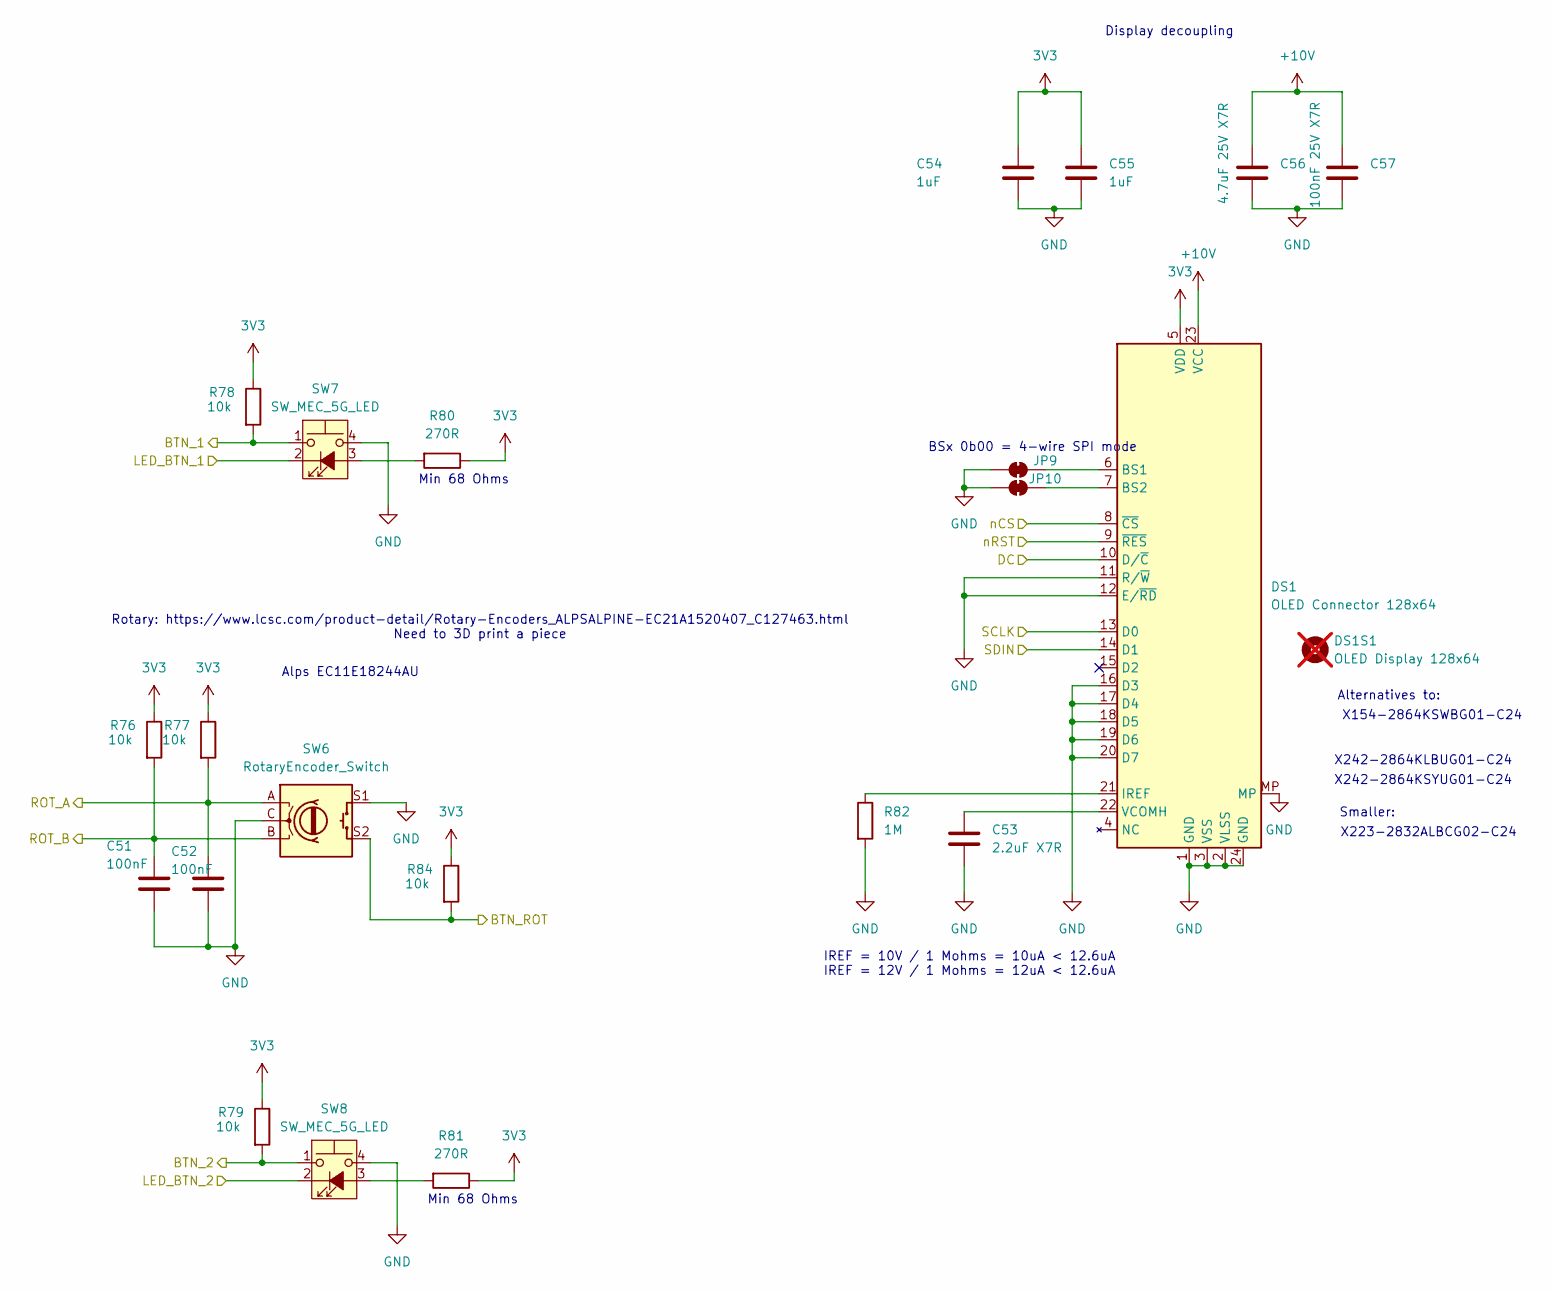
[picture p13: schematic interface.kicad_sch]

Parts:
C51, C52: 100nF; C_0402_1005Metric; JLC 0402
C53: 2.2uF X7R; C_0805_2012Metric; JLC 0805
C54, C55: 1uF; C_0805_2012Metric; JLC 0805
C56: 4.7uF 25V X7R; C_0805_2012Metric; JLC 0805
C57: 100nF 25V X7R; C_0805_2012Metric; JLC 0805
DS1: OLED Connector 128x64; Hirose_FH52-24S-0.5SH_1x24-1MP_P0.5mm_Horizontal; LCSC C5378714
DS1S1: OLED Display 128x64; OLED-128O064D; LCSC C5123567; not fitted
JP9, JP10: SolderJumper_2_Bridged; SolderJumper_0402_1005Metric_Bridged
R76, R77, R78, R79, R84: 10k; R_0402_1005Metric; JLC 0402
R80, R81: 270R; R_0402_1005Metric; JLC 0402
R82: 1M; R_0402_1005Metric; JLC 0402
SW6: RotaryEncoder_Switch; RotaryEncoder_Alps_EC11E-Switch_Vertical_H20mm; LCSC C202365
SW7, SW8: SW_MEC_5G_LED; TPB01-X0XLXX_SW_MEC_5G; LCSC C2762115

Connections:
3V3: C54.1, C55.1, DS1.5 (VDD), R76.1, R77.1, R78.1, R79.1, R80.1, R81.1, R84.1; also elsewhere on the board
+10V: C56.1, C57.1, DS1.23 (VCC); also elsewhere on the board
/Interface/BTN_1: R78.2, SW7.1; also elsewhere on the board
/Interface/BTN_2: R79.2, SW8.1; also elsewhere on the board
/Interface/BTN_ROT: R84.2, SW6.S2; also elsewhere on the board
/Interface/DC: DS1.10 (D/~C); also elsewhere on the board
/Interface/LED_BTN_1: SW7.2; also elsewhere on the board
/Interface/LED_BTN_2: SW8.2; also elsewhere on the board
/Interface/ROT_A: C52.1, R77.2, SW6.A; also elsewhere on the board
/Interface/ROT_B: C51.1, R76.2, SW6.B; also elsewhere on the board
/Interface/SDIN: DS1.14 (D1); also elsewhere on the board
/Interface/nCS: DS1.8 (~CS); also elsewhere on the board
/Interface/nRST: DS1.9 (~RES); also elsewhere on the board
/Soc/SPI4_SCK: DS1.13 (D0); also elsewhere on the board
GND: C51.2, C52.2, C53.2, C54.2, C55.2, C56.2, C57.2, DS1.1 (GND), DS1.2 (VLSS), DS1.3 (VSS), DS1.11 (R/~W), DS1.12 (E/~RD), DS1.16 (D3), DS1.17 (D4), DS1.18 (D5), DS1.19 (D6), DS1.20 (D7), DS1.24 (GND), DS1.MP, JP9.1 (A), JP10.1 (A), R82.2, SW6.C, SW6.S1, SW7.4 (A), SW8.4 (A); also elsewhere on the board
unnamed: DS1.6 (BS1), JP9.2 (B)
unnamed: DS1.7 (BS2), JP10.2 (B)
unnamed: DS1.21 (IREF), R82.1
unnamed: C53.1, DS1.22 (VCOMH)
unnamed: R80.2, SW7.3 (K)
unnamed: R81.2, SW8.3 (K)

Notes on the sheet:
X242-2864KLBUG01-C24
Display decoupling
Smaller:
X154-2864KSWBG01-C24
Alps EC11E18244AU
X242-2864KSYUG01-C24
X223-2832ALBCG02-C24
Min 68 Ohms
IREF = 10V / 1 Mohms = 10uA < 12.6uA IREF = 12V / 1 Mohms = 12uA < 12.6uA
BSx 0b00 = 4-wire SPI mode
Alternatives to:
Rotary: https://www.lcsc.com/product-detail/Rotary-Encoders_ALPSALPINE-EC21A1520407_C127463.html Need to 3D print a piece

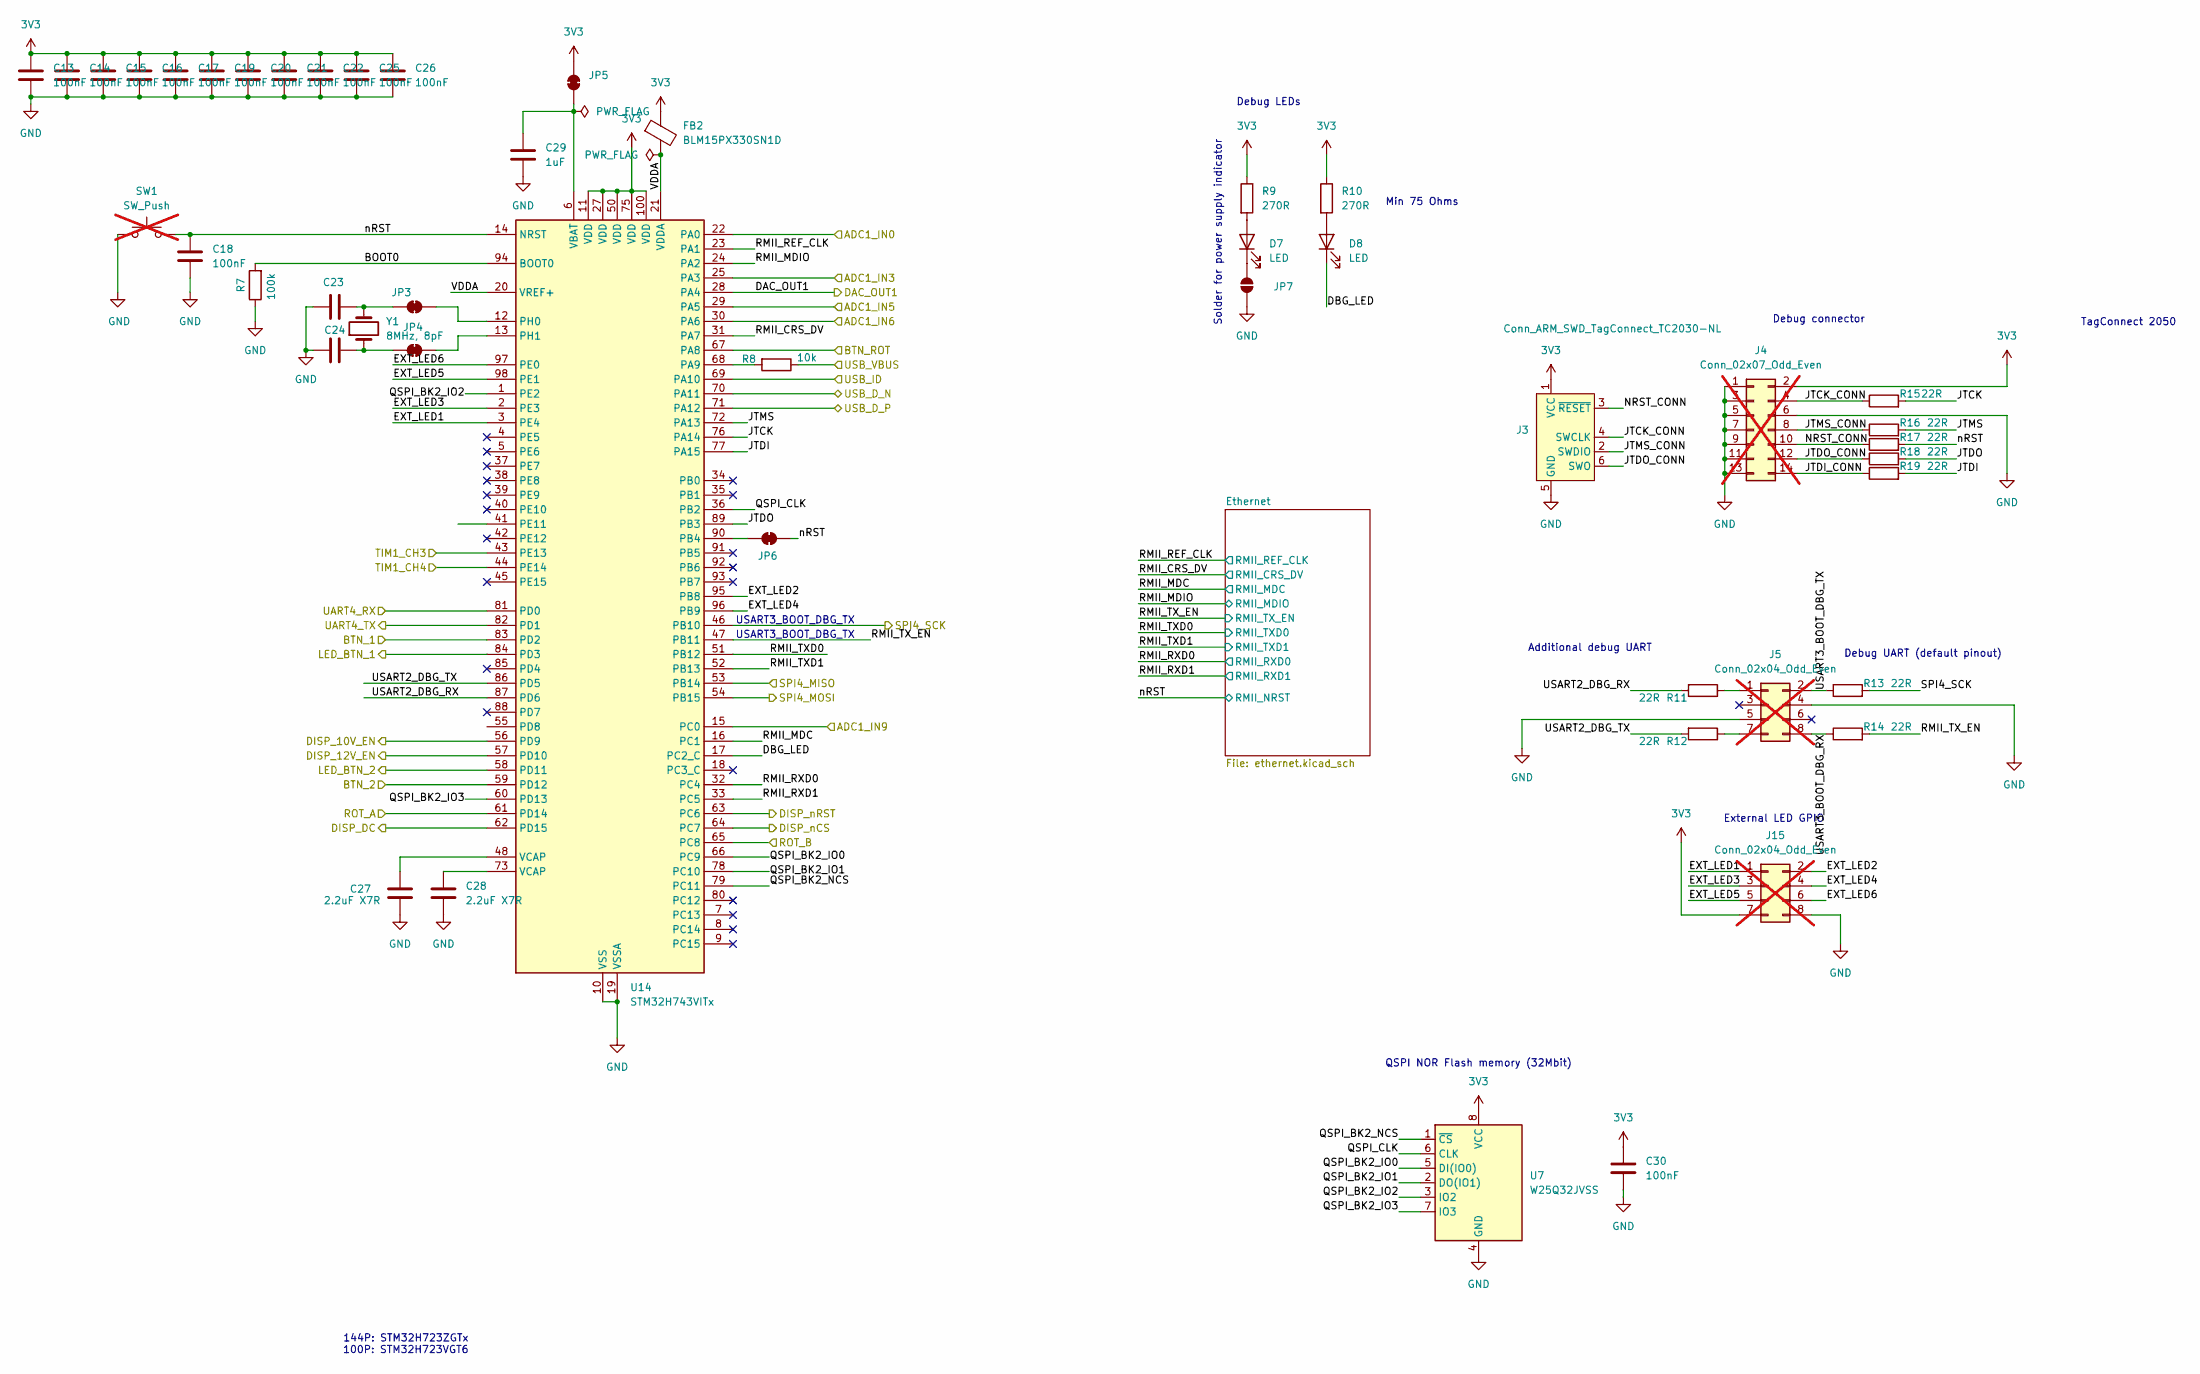
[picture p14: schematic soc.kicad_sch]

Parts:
C13, C14, C15, C16, C17, C18, C19, C20, C21, C22, C25, C26, C30: 100nF; C_0402_1005Metric; JLC 0402
C23, C24: 4.3pF; C_0402_1005Metric; JLC 0402
C27, C28: 2.2uF X7R; C_0805_2012Metric; JLC 0805
C29: 1uF; C_0805_2012Metric; JLC 0805
D7, D8: LED; LED_0805_2012Metric; JLC 0805
FB2: BLM15PX330SN1D; L_0402_1005Metric; LCSC C160974
J3: Conn_ARM_SWD_TagConnect_TC2030-NL; Tag-Connect_TC2030-IDC-NL_2x03_P1.27mm_Vertical
J4: Conn_02x07_Odd_Even; PinSocket_2x07_P2.54mm_Vertical_SMD; LCSC C84004; not fitted
J5, J15: Conn_02x04_Odd_Even; PinHeader_2x04_P2.54mm_Vertical_SMD; LCSC C192300; not fitted
JP3, JP4, JP5, JP6: SolderJumper_2_Bridged; SolderJumper_0402_1005Metric_Bridged
JP7: SolderJumper_2_Open; R_0402_1005Metric
R7: 100k; R_0402_1005Metric; JLC 0402
R8: 10k; R_0402_1005Metric; JLC 0402
R9, R10: 270R; R_0402_1005Metric; JLC 0402
R11, R12, R13, R14, R15, R16, R17, R18, R19: 22R; R_0402_1005Metric; JLC 0402
SW1: SW_Push; SW_SPST_B3S-1000; LCSC C5127964; not fitted
U7: W25Q32JVSS; SOIC-8_5.23x5.23mm_P1.27mm; LCSC C179173
U14: STM32H743VITx; LQFP-100_14x14mm_P0.5mm; LCSC C114409
Y1: 8MHz, 8pF; Crystal_SMD_3225-2Pin_3.2x2.5mm; LCSC C889706

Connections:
3V3: C13.1, C14.1, C15.1, C16.1, C17.1, C19.1, C20.1, C21.1, C22.1, C25.1, C26.1, C30.1, FB2.1, J3.1 (VCC), J4.2, J15.7, JP5.2 (B), R9.1, R10.1, U7.8 (VCC), U14.11 (VDD), U14.27 (VDD), U14.50 (VDD), U14.75 (VDD), U14.100 (VDD); also elsewhere on the board
/Analog_in/CVIN0: U14.22 (PA0); also elsewhere on the board
/Analog_in/CVIN1: U14.25 (PA3); also elsewhere on the board
/Analog_in/CVIN2: U14.29 (PA5); also elsewhere on the board
/Analog_in/CVIN3: U14.30 (PA6); also elsewhere on the board
/Analog_in/TRG0: U14.43 (PE13); also elsewhere on the board
/Analog_in/TRG1: U14.44 (PE14); also elsewhere on the board
/Interface/BTN_1: U14.83 (PD2); also elsewhere on the board
/Interface/BTN_2: U14.59 (PD12); also elsewhere on the board
/Interface/BTN_ROT: U14.67 (PA8); also elsewhere on the board
/Interface/DC: U14.62 (PD15); also elsewhere on the board
/Interface/LED_BTN_1: U14.84 (PD3); also elsewhere on the board
/Interface/LED_BTN_2: U14.58 (PD11); also elsewhere on the board
/Interface/ROT_A: U14.61 (PD14); also elsewhere on the board
/Interface/ROT_B: U14.65 (PC8); also elsewhere on the board
/Interface/SDIN: U14.54 (PB15); also elsewhere on the board
/Interface/nCS: U14.64 (PC7); also elsewhere on the board
/Interface/nRST: U14.63 (PC6); also elsewhere on the board
/Midi_in/MIDI_TO_SOC: U14.81 (PD0); also elsewhere on the board
/Soc/ADC1_IN9: U14.15 (PC0); also elsewhere on the board
/Soc/BOOT0: R7.2, U14.94 (BOOT0)
/Soc/DAC_OUT1: U14.28 (PA4); also elsewhere on the board
/Soc/DBG_LED: D8.1 (K), U14.17 (PC2_C)
/Soc/DISP_10V_EN: U14.56 (PD9); also elsewhere on the board
/Soc/DISP_12V_EN: U14.57 (PD10); also elsewhere on the board
/Soc/EXT_LED1: J15.1, U14.3 (PE4)
/Soc/EXT_LED2: J15.2, U14.95 (PB8)
/Soc/EXT_LED3: J15.3, U14.2 (PE3)
/Soc/EXT_LED4: J15.4, U14.96 (PB9)
/Soc/EXT_LED5: J15.5, U14.98 (PE1)
/Soc/EXT_LED6: J15.6, U14.97 (PE0)
/Soc/JTCK: R15.2, U14.76 (PA14)
/Soc/JTCK_CONN: J3.4 (SWCLK), J4.4, R15.1
/Soc/JTDI: R19.2, U14.77 (PA15)
/Soc/JTDI_CONN: J4.14, R19.1
/Soc/JTDO: R18.2, U14.89 (PB3)
/Soc/JTDO_CONN: J3.6 (SWO), J4.12, R18.1
/Soc/JTMS: R16.2, U14.72 (PA13)
/Soc/JTMS_CONN: J3.2 (SWDIO), J4.8, R16.1
/Soc/NRST_CONN: J3.3 (~RESET), J4.10, R17.1
/Soc/QSPI_BK2_IO0: U7.5 (DI(IO0)), U14.66 (PC9)
/Soc/QSPI_BK2_IO1: U7.2 (DO(IO1)), U14.78 (PC10)
/Soc/QSPI_BK2_IO2: U7.3 (IO2), U14.1 (PE2)
/Soc/QSPI_BK2_IO3: U7.7 (IO3), U14.60 (PD13)
/Soc/QSPI_BK2_NCS: U7.1 (~CS), U14.79 (PC11)
/Soc/QSPI_CLK: U7.6 (CLK), U14.36 (PB2)
/Soc/RMII_CRS_DV: U14.31 (PA7); also elsewhere on the board
/Soc/RMII_MDC: U14.16 (PC1); also elsewhere on the board
/Soc/RMII_MDIO: U14.24 (PA2); also elsewhere on the board
/Soc/RMII_REF_CLK: U14.23 (PA1); also elsewhere on the board
/Soc/RMII_RXD0: U14.32 (PC4); also elsewhere on the board
/Soc/RMII_RXD1: U14.33 (PC5); also elsewhere on the board
/Soc/RMII_TXD0: U14.51 (PB12); also elsewhere on the board
/Soc/RMII_TXD1: U14.52 (PB13); also elsewhere on the board
/Soc/RMII_TX_EN: R14.2, U14.47 (PB11); also elsewhere on the board
/Soc/SPI4_MISO: U14.53 (PB14); also elsewhere on the board
/Soc/SPI4_SCK: R13.2, U14.46 (PB10); also elsewhere on the board
/Soc/UART4_TX: U14.82 (PD1); also elsewhere on the board
/Soc/USART2_DBG_RX: R11.2, U14.87 (PD6)
/Soc/USART2_DBG_TX: R12.2, U14.86 (PD5)
/Soc/USART3_BOOT_DBG_RX: J5.8, R14.1
/Soc/USART3_BOOT_DBG_TX: J5.2, R13.1
/Soc/USB_D_N: U14.70 (PA11); also elsewhere on the board
/Soc/USB_D_P: U14.71 (PA12); also elsewhere on the board
/Soc/USB_ID: U14.69 (PA10); also elsewhere on the board
/Soc/VDDA: FB2.2, U14.20 (VREF+), U14.21 (VDDA)
/Soc/nRST: C18.1, JP6.1 (A), R17.2, SW1.2, U14.14 (NRST); also elsewhere on the board
/Supply/VBUS: R8.1; also elsewhere on the board
GND: C13.2, C14.2, C15.2, C16.2, C17.2, C18.2, C19.2, C20.2, C21.2, C22.2, C23.1, C24.1, C25.2, C26.2, C27.2, C28.2, C29.2, C30.2, J3.5 (GND), J4.1, J4.3, J4.5, J4.6, J4.7, J4.9, J4.11, J4.13, J5.4, J5.5, J15.8, JP7.1 (A), R7.1, SW1.1, U7.4 (GND), U14.10 (VSS), U14.19 (VSSA), U14.26 (VSS), U14.49 (VSS), U14.74 (VSS), U14.99 (VSS); also elsewhere on the board
unnamed: C27.1, U14.48 (VCAP)
unnamed: C28.1, U14.73 (VCAP)
unnamed: D7.2 (A), R9.2
unnamed: D7.1 (K), JP7.2 (B)
unnamed: D8.2 (A), R10.2
unnamed: J5.1, R11.1
unnamed: J5.7, R12.1
unnamed: JP3.1 (A), U14.12 (PH0)
unnamed: C23.2, JP3.2 (B), Y1.2
unnamed: JP4.1 (A), U14.13 (PH1)
unnamed: C24.2, JP4.2 (B), Y1.1
unnamed: C29.1, JP5.1 (A), U14.6 (VBAT)
unnamed: JP6.2 (B), U14.90 (PB4)
unnamed: R8.2, U14.68 (PA9)

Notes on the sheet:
Debug connector
USART3_BOOT_DBG_TX
Min 75 Ohms
TagConnect 2050
Debug LEDs
QSPI NOR Flash memory (32Mbit)
External LED GPIO
144P: STM32H723ZGTx 100P: STM32H723VGT6
Debug UART (default pinout)
Additional debug UART
Solder for power supply indicator

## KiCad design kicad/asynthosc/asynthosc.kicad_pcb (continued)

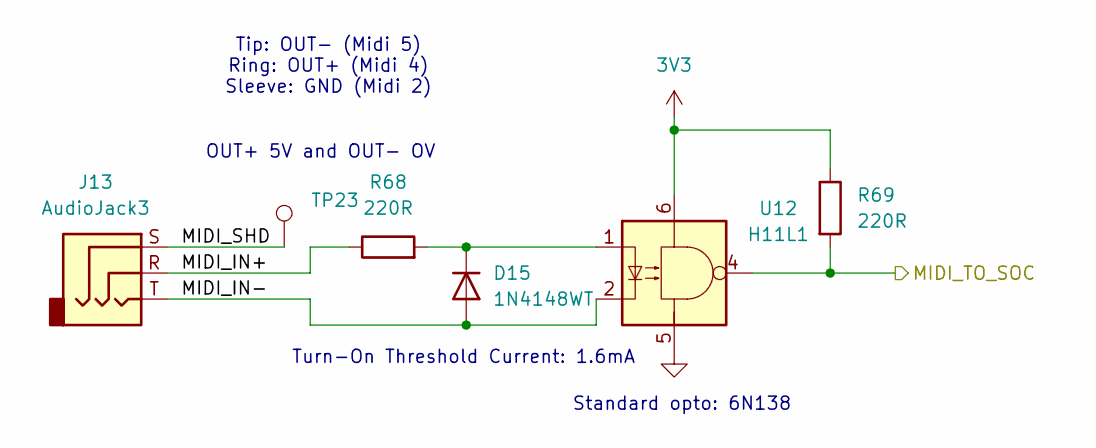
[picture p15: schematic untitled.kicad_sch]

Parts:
D15: 1N4148WT; D_SOD-523; LCSC C232841
J13: AudioJack3; Jack_3.5mm_3legs_XKB_PJ-3411_Vertical; LCSC C381132
R68, R69: 220R; R_0402_1005Metric; JLC 0402
TP23: TestPoint; TestPoint_Pad_D1.0mm
U12: H11L1; SMDIP-6_W9.53mm; LCSC C22376095

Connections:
3V3: R69.1, U12.6; also elsewhere on the board
/Midi_in/MIDI_IN+: J13.R, R68.1
/Midi_in/MIDI_IN-: D15.2 (A), J13.T, U12.2
/Midi_in/MIDI_SHD: J13.S, TP23.1
/Midi_in/MIDI_TO_SOC: R69.2, U12.4; also elsewhere on the board
GND: U12.5; also elsewhere on the board
unnamed: D15.1 (K), R68.2, U12.1

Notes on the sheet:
Tip: OUT- (Midi 5) Ring: OUT+ (Midi 4) Sleeve: GND (Midi 2)
OUT+ 5V and OUT- OV
Standard opto: 6N138
Turn-On Threshold Current: 1.6mA

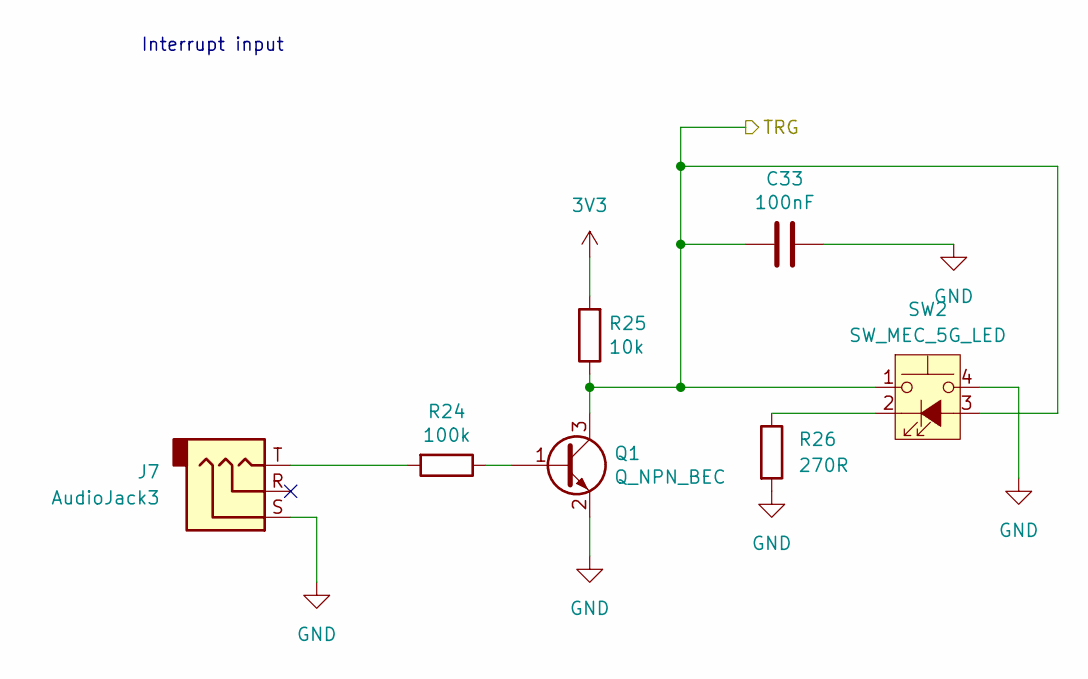
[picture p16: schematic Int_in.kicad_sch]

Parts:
C33: 100nF; C_0603_1608Metric; JLC 0603
J7: AudioJack3; Jack_3.5mm_3legs_XKB_PJ-3411_Vertical; LCSC C381132
Q1: Q_NPN_BEC; SOT-23; LCSC C18221467
R24: 100k; R_0402_1005Metric; JLC 0402
R25: 10k; R_0402_1005Metric; JLC 0402
R26: 270R; R_0402_1005Metric; JLC 0402
SW2: SW_MEC_5G_LED; TPB01-X0XLXX_SW_MEC_5G; LCSC C2762115

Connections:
3V3: R25.2; also elsewhere on the board
/Analog_in/TRG1: C33.2, Q1.3 (C), R25.1, SW2.1, SW2.3 (K); also elsewhere on the board
GND: C33.1, J7.S, Q1.2 (E), R26.2, SW2.4 (A); also elsewhere on the board
unnamed: J7.T, R24.2
unnamed: Q1.1 (B), R24.1
unnamed: R26.1, SW2.2

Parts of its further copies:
C37: 100nF; C_0603_1608Metric; JLC 0603
J11: AudioJack3; Jack_3.5mm_3legs_XKB_PJ-3411_Vertical; LCSC C381132
Q2: Q_NPN_BEC; SOT-23; LCSC C18221467
R45: 100k; R_0402_1005Metric; JLC 0402
R46: 10k; R_0402_1005Metric; JLC 0402
R47: 270R; R_0402_1005Metric; JLC 0402
SW5: SW_MEC_5G_LED; TPB01-X0XLXX_SW_MEC_5G; LCSC C2762115

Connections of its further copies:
3V3: R46.2; also elsewhere on the board
/Analog_in/TRG0: C37.2, Q2.3 (C), R46.1, SW5.1, SW5.3 (K); also elsewhere on the board
GND: C37.1, J11.S, Q2.2 (E), R47.2, SW5.4 (A); also elsewhere on the board
unnamed: J11.T, R45.2
unnamed: Q2.1 (B), R45.1
unnamed: R47.1, SW5.2

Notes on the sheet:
Interrupt input

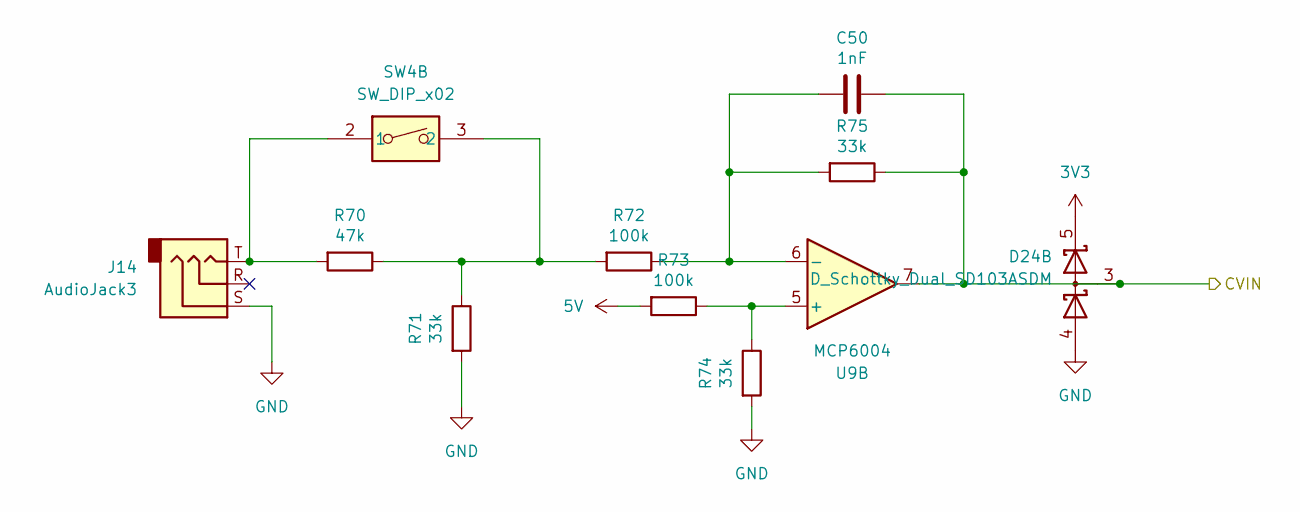
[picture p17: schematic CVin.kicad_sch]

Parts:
C50: 1nF; C_0603_1608Metric; JLC 0603
D24: D_Schottky_Dual_SD103ASDM; SOT-23-6; LCSC C154909
J14: AudioJack3; Jack_3.5mm_3legs_XKB_PJ-3411_Vertical; LCSC C381132
R70: 47k; R_0402_1005Metric; JLC 0402
R71, R74, R75: 33k; R_0402_1005Metric; JLC 0402
R72, R73: 100k; R_0402_1005Metric; JLC 0402
SW4: SW_DIP_x02; SW_DIP_SPSTx02_Slide_9.78x7.26mm_W8.61mm_P2.54mm; LCSC C18198124
U9: MCP6004; TSSOP-14_4.4x5mm_P0.65mm; LCSC C627416

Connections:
3V3: D24.2 (K), D24.5 (K); also elsewhere on the board
5V: R73.2; also elsewhere on the board
/Analog_in/CVIN2: D24.6 (common), U9.1; also elsewhere on the board
/Analog_in/CVIN3: C50.1, D24.3 (common), R75.1, U9.7; also elsewhere on the board
GND: D24.1 (A), D24.4 (A), J14.S, R71.2, R74.2; also elsewhere on the board
unnamed 115: SW4.1; also elsewhere on the board
unnamed 138: SW4.4 (2); also elsewhere on the board
unnamed: J14.T, R70.2, SW4.2 (1)
unnamed: R70.1, R71.1, R72.2, SW4.3 (2)
unnamed 153: U9.3 (+); also elsewhere on the board
unnamed 154: U9.2 (-); also elsewhere on the board
unnamed: R73.1, R74.1, U9.5 (+)
unnamed: C50.2, R72.1, R75.2, U9.6 (-)

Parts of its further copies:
C34, C35, C36: 1nF; C_0603_1608Metric; JLC 0603
D22: D_Schottky_Dual_SD103ASDM; SOT-23-6; LCSC C154909
J8, J9, J10: AudioJack3; Jack_3.5mm_3legs_XKB_PJ-3411_Vertical; LCSC C381132
R27, R33, R39: 47k; R_0402_1005Metric; JLC 0402
R28, R31, R32, R34, R37, R38, R40, R43, R44: 33k; R_0402_1005Metric; JLC 0402
R29, R30, R35, R36, R41, R42: 100k; R_0402_1005Metric; JLC 0402
SW3: SW_DIP_x02; SW_DIP_SPSTx02_Slide_9.78x7.26mm_W8.61mm_P2.54mm; LCSC C18198124

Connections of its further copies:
3V3: D22.2 (K), D22.5 (K); also elsewhere on the board
5V: R30.2, R36.2, R42.2; also elsewhere on the board
/Analog_in/CVIN0: C34.1, D22.6 (common), R32.1; also elsewhere on the board
/Analog_in/CVIN1: C35.1, D22.3 (common), R38.1; also elsewhere on the board
/Analog_in/CVIN2: C36.1, R44.1; also elsewhere on the board
GND: D22.1 (A), D22.4 (A), J8.S, J9.S, J10.S, R28.2, R31.2, R34.2, R37.2, R40.2, R43.2; also elsewhere on the board
unnamed: J8.T, R27.2, SW3.1
unnamed 115: J10.T, R39.2; also elsewhere on the board
unnamed: R27.1, R28.1, R29.2, SW3.4 (2)
unnamed: J9.T, R33.2, SW3.2 (1)
unnamed: R33.1, R34.1, R35.2, SW3.3 (2)
unnamed 138: R39.1, R40.1, R41.2; also elsewhere on the board
unnamed 148: R30.1, R31.1; also elsewhere on the board
unnamed 149: C34.2, R29.1, R32.2; also elsewhere on the board
unnamed 150: R36.1, R37.1; also elsewhere on the board
unnamed 151: C35.2, R35.1, R38.2; also elsewhere on the board
unnamed 153: R42.1, R43.1; also elsewhere on the board
unnamed 154: C36.2, R41.1, R44.2; also elsewhere on the board

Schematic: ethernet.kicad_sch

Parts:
C38, C39: 30pF; C_0402_1005Metric; JLC 0402
C40: 470pF; C_0402_1005Metric; JLC 0402
C41: 1uF; C_0805_2012Metric; JLC 0805
C42, C43, C44, C46, C47, C49: 100nF; C_0402_1005Metric; JLC 0402
C45: 10uF; CP_Elec_4x5.4; LCSC C72485
C48: 1nF X7R; C_0402_1005Metric; JLC 0402
FB3: BLM15PX330SN1D; L_0402_1005Metric; LCSC C160974
J12: RJ45_LED_Shielded; RJ45_CKMTW_R-RJ45S08P-C000_Vertical; LCSC C386764
JP8: SolderJumper_2_Bridged; SolderJumper_0402_1005Metric_Bridged
R48, R49, R50: 100k; R_0402_1005Metric; JLC 0402
R51: 1.5K; R_0402_1005Metric; JLC 0402
R52, R53, R54, R55, R56: 33R; R_0402_1005Metric; JLC 0402
R57, R59, R60, R61: 50R; R_0402_1005Metric; JLC 0402
R58: 12.1k; R_0402_1005Metric; JLC 0402
R62, R63, R64, R65: 75R; R_0402_1005Metric; JLC 0402
R66, R67: 270R; R_0402_1005Metric; JLC 0402
TR1: PT61017PEL; Transformer_Ethernet_Bourns_PT61017PEL; LCSC C124001
U10: LAN8742A; VQFN-24-1EP_4x4mm_P0.5mm_EP2.5x2.5mm_ThermalVias; LCSC C633284
U11, U13: USBLC6-2P6; SOT-666; LCSC C15999
Y3: 25MHZ,20PF,30PPM; Crystal_SMD_3225-4Pin_3.2x2.5mm; LCSC C9006

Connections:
3V3: C40.1, C41.1, C42.1, FB3.2, R48.2, R49.2, R50.2, R51.2, U10.6 (VDDCR), U10.9 (VDDIO); also elsewhere on the board
3V3_FILT: C43.1, C44.1, C45.1, C46.1, C47.1, C49.1, FB3.1, R57.2, R59.2, R60.2, R61.2, TR1.2 (C_TD), TR1.7 (C_RD), U10.1 (VDD2A), U10.19 (VDD1A), U11.5 (VBUS), U13.5 (VBUS)
/Soc/Ethernet/RJ45_LED1: J12.12, U10.3 (LED1/REGOFF)
/Soc/Ethernet/RJ45_LED2: J12.10, U10.2 (LED2/~INTSEL)
/Soc/Ethernet/RJ_RX_N: J12.6, TR1.16 (TX+)
/Soc/Ethernet/RJ_RX_P: J12.3, TR1.14 (TX-)
/Soc/Ethernet/RJ_TX_N: J12.2, TR1.11 (RX+)
/Soc/Ethernet/RJ_TX_P: J12.1, TR1.9 (RX-)
/Soc/Ethernet/RX_N: R57.1, U10.22 (RXN), U11.3 (I/O2)
/Soc/Ethernet/RX_P: R59.1, U10.23 (RXP), U11.1 (I/O1)
/Soc/Ethernet/RX_S_N: TR1.1 (TD+), U11.4 (I/O2)
/Soc/Ethernet/RX_S_P: TR1.3 (TD-), U11.6 (I/O1)
/Soc/Ethernet/TX_N: R60.1, U10.20 (TXN), U13.3 (I/O2)
/Soc/Ethernet/TX_P: R61.1, U10.21 (TXP), U13.1 (I/O1)
/Soc/Ethernet/TX_S_N: TR1.6 (RD+), U13.4 (I/O2)
/Soc/Ethernet/TX_S_P: TR1.8 (RD-), U13.6 (I/O1)
/Soc/RMII_CRS_DV: R55.1; also elsewhere on the board
/Soc/RMII_MDC: U10.13 (MDC); also elsewhere on the board
/Soc/RMII_MDIO: R51.1, U10.12 (MDIO); also elsewhere on the board
/Soc/RMII_REF_CLK: R50.1, R56.1; also elsewhere on the board
/Soc/RMII_RXD0: R48.1, R52.1; also elsewhere on the board
/Soc/RMII_RXD1: R49.1, R53.1; also elsewhere on the board
/Soc/RMII_TXD0: U10.17 (TXD0); also elsewhere on the board
/Soc/RMII_TXD1: U10.18 (TXD1); also elsewhere on the board
/Soc/RMII_TX_EN: U10.16 (TXEN); also elsewhere on the board
/Soc/nRST: JP8.2 (B); also elsewhere on the board
GND: C38.1, C39.1, C40.2, C41.2, C42.2, C43.2, C44.2, C45.2, C46.2, C47.2, C48.2, C49.2, J12.SH, R54.1, R58.2, R66.1, R67.1, U10.25 (VSS), U11.2 (GND), U13.2 (GND), Y3.2, Y3.4; also elsewhere on the board
unnamed: C48.1, R62.1, R63.1, R64.1, R65.1
unnamed: J12.4, J12.5, R64.2
unnamed: J12.7, J12.8, R65.2
unnamed: J12.9, R66.2
unnamed: J12.11, R67.2
unnamed: JP8.1 (A), U10.15 (~RST)
unnamed: R63.2, TR1.10 (C_RX)
unnamed: R62.2, TR1.15 (C_TX)
unnamed: R55.2, U10.11 (CRS_DV/MODE2)
unnamed: R58.1, U10.24 (RBIAS)
unnamed: R52.2, U10.8 (RXD0/MODE0)
unnamed: R53.2, U10.7 (RXD1/MODE1)
unnamed: R54.2, U10.10 (RXER/PHYAD0)
unnamed: C38.2, U10.5 (XTAL1/CLKIN), Y3.1
unnamed: C39.2, U10.4 (XTAL2), Y3.3
unnamed: R56.2, U10.14 (~INT/REFCLKO)

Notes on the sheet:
bead,600R,350mA,0603,FCM1608KF-601T05

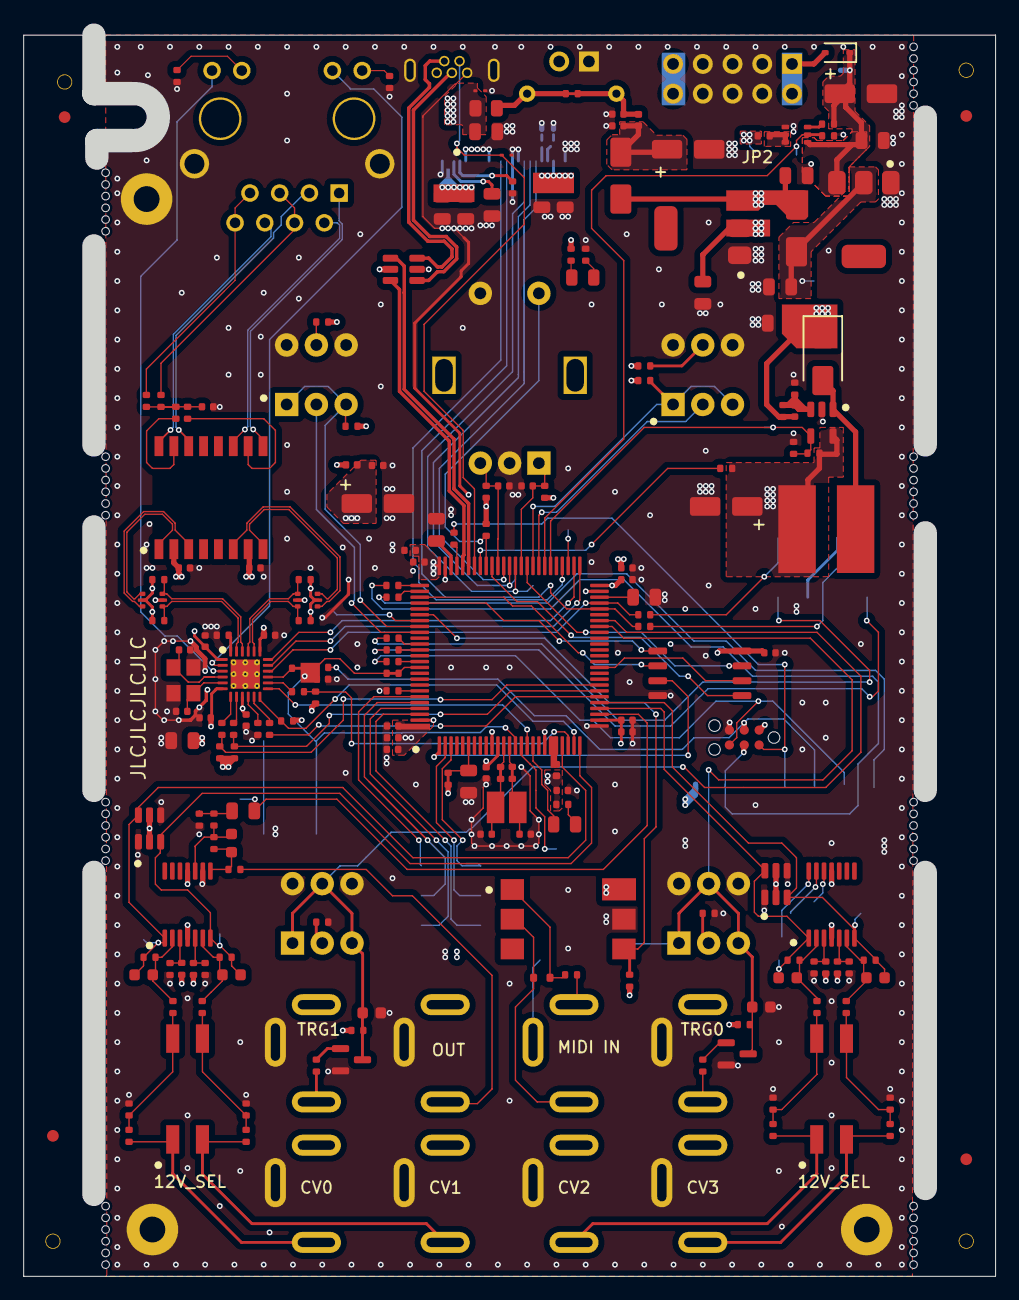
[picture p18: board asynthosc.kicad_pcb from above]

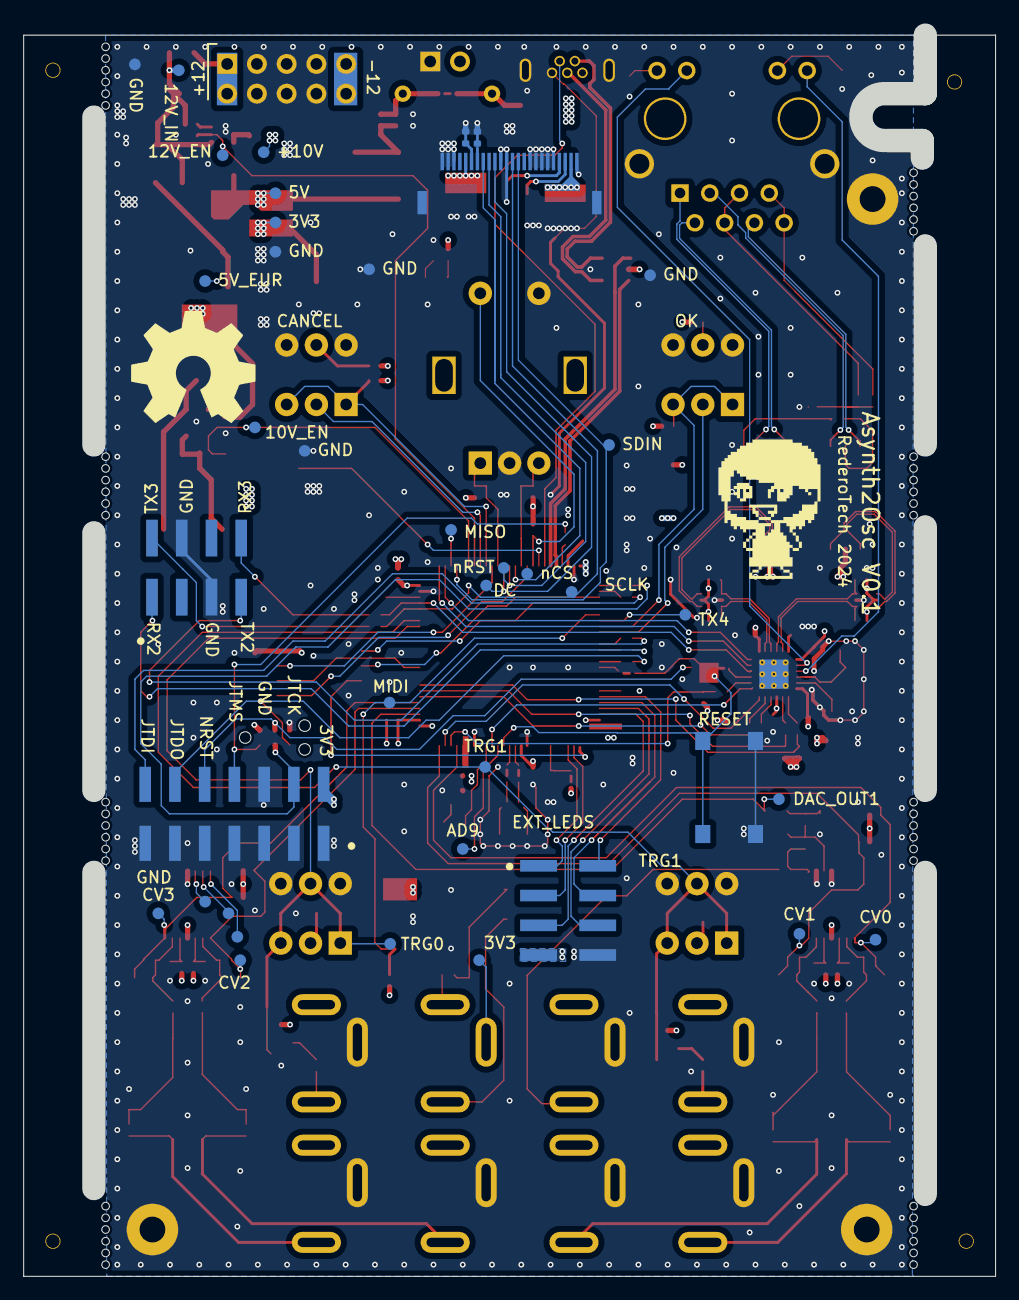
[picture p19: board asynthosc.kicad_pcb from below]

Board: 4 copper layers, 83.0 x 106.0 mm, 261 parts (53 on the bottom side), 168 nets.

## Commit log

2024-01-23 doc: adding a draft bom
    [bom.csv]
2024-05-05 wip: update bom and description
    [bom.csv]
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2024-05-20 wip: esp32 bom update
    [bom.csv]
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2024-05-21 doc: add dac comparison, fix architecture drawing with stm32
2024-06-09 bom: optional 100-pins stm32
    [bom_stm32.csv]
2024-08-02 sch: add kicad files
    [analog_in.kicad_sch, asynthosc.kicad_pcb, asynthosc.kicad_sch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]
2024-08-02 sch: wip, add .gitignore
    [analog_in.kicad_sch, misc.kicad_sch, soc.kicad_sch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]
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2024-08-06 sch: basic stm32 with power, clocks and debug
    [ethernet.kicad_sch, soc.kicad_sch, supply.kicad_sch]
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2024-08-07 sch: top sheet pins input
    [asynthosc.kicad_sch, soc.kicad_sch]
2024-08-08 sch: update and new interface sheet
    [analog_in.kicad_sch, asynthosc.kicad_sch, ethernet.kicad_sch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]
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2024-08-09 sch: add spi nor, display connection, and more footprints
    [CVin.kicad_sch, Int_in.kicad_sch, analog_in.kicad_sch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]
2024-08-09 sch: power supply improvements
    [asynthosc.kicad_sch, soc.kicad_sch, supply.kicad_sch]
2024-08-09 sch: update footprint links
    [CVin.kicad_sch, Int_in.kicad_sch, analog_in.kicad_sch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]
2024-08-13 sch: change stm32 for smaller one, create smaller jumper footprint
    [CVin.kicad_sch, Int_in.kicad_sch, analog_in.kicad_sch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]
2024-08-13 bom: update bom for lcsc
    [CVin.kicad_sch, Int_in.kicad_sch, analog_in.kicad_sch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]
2024-08-13 sch: dip switch with separated sym
    [CVin.kicad_sch, asynthosc.kicad_pcb]
2024-08-13 [sch][brd] Fix RJ45 footprint
    [asynthosc.kicad_pcb]
2024-08-13 brd: move connectors to bot (components will be on bottom, connectors on top)
    [asynthosc.kicad_pcb]
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2024-09-01 pcb: place and change some components for easier routing
    [CVin.kicad_sch, Int_in.kicad_sch, analog_in.kicad_sch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]
2024-09-17 pcb: moving graphical elements
    [asynthosc.kicad_pcb]
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2024-09-17 pcb: place and draft route
    [CVin.kicad_sch, asynthosc.kicad_pcb, asynthosc.kicad_sch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]
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2024-09-17 sch: pcb: fix pin errors
    [analog_in.kicad_sch, asynthosc.kicad_pcb, ethernet.kicad_sch]
2024-09-17 sch: pcb: tiny fixes and changes
    [analog_in.kicad_sch, asynthosc.kicad_pcb, asynthosc.kicad_sch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]
2024-09-17 sch: pcb: add gpio output connector for optional LEDs on decorative board
    [asynthosc.kicad_pcb, soc.kicad_sch]
2024-09-17 sch: pcb: wip and silkscreen cleaning
    [asynthosc.kicad_pcb, asynthosc.kicad_sch, soc.kicad_sch]
2024-09-17 sch: pcb: fix: footprint mismatches
    [CVin.kicad_sch, asynthosc.kicad_pcb, asynthosc.kicad_sch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]
2024-09-17 pcb: route, add some silkscreen
    [asynthosc.kicad_pcb, ethernet.kicad_sch, soc.kicad_sch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]
2024-09-17 pcb: fix mechanical issues after easyeda simulation
    [asynthosc.kicad_pcb]
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2024-09-17 pcb: sch: drown mp pad in gnd for display connector
    [asynthosc.kicad_pcb, interface.kicad_sch]
2024-09-17 pcb: configure jlc 4-layer stackup
    [asynthosc.kicad_pcb]
2024-09-17 drc: fix min via crown size
    [asynthosc.kicad_pcb]
2024-09-17 sch: alternative displays. pcb: wip
    [asynthosc.kicad_pcb, interface.kicad_sch]
2024-09-17 pcb: add diff pair values
    [asynthosc.kicad_pcb, yarns_contour.kicad_pcb]
2024-09-17 comp: add vertical usb micro-b and rj45 footprints
    [asynthosc.kicad_pcb, ethernet.kicad_sch, supply.kicad_sch]
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2024-09-17 pcb: fix some drc
    [asynthosc.kicad_pcb]
2024-09-17 pcb: fix some more drc
    [asynthosc.kicad_pcb, ethernet.kicad_sch]
2024-09-17 pcb: fix drc
    [asynthosc.kicad_pcb]
2024-09-17 pcb: drc and antenna fix
    [asynthosc.kicad_pcb]
2024-09-17 pcb: sch: panel: add panelisation for pcba assembly
    [asynthosc.kicad_sch]
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2024-09-17 pcb: add design rules to match jlc pcba assembly rules. sch: fix a 0805 package mishap
    [asynthosc.kicad_pcb, supply.kicad_sch, yarns_contour.kicad_pcb]
2024-09-17 sch: change stm32 ref for adc
    [asynthosc.kicad_pcb, soc.kicad_sch]
2024-09-17 bom: update mfr, serials and lcsc fields
    [CVin.kicad_sch, Int_in.kicad_sch, analog_in.kicad_sch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]
2024-09-17 bom: sch: pcb: update for sourcing in jlc pcba services
    [CVin.kicad_sch, asynthosc.kicad_pcb, interface.kicad_sch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]
2024-09-17 bom: update for better bom
    [asynthosc.kicad_pcb, asynthosc.kicad_sch, ethernet.kicad_sch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]
2024-09-17 pcb: board outline and milling update
    [asynthosc.kicad_pcb]
2024-09-17 pcb: change export option for jlc
    [asynthosc.kicad_pcb]
2024-09-17 pcb: update drc from jlc
    [asynthosc.kicad_pcb]
2024-09-17 pcb: export place file
    [asynthosc.kicad_pcb]
2024-09-17 sch: pcb: change stm32 gpio pinout to h7
    [asynthosc.kicad_pcb, soc.kicad_sch]
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2024-09-17 pcb: more design rules
    [asynthosc.kicad_pcb]
2024-09-17 bom: add jlcpcb field with simplified footprint
    [CVin.kicad_sch, Int_in.kicad_sch, analog_in.kicad_sch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]
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2024-09-17 sch: add no connect indicators
    [soc.kicad_sch]
2024-09-17 pcb: replace display connector
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2024-09-17 pcb: bom: comp: misc fixes, button footprint, and move usb-b away from rj45
    [interface.kicad_sch]
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2024-09-17 bom: dnp for all manually equiped components
    [CVin.kicad_sch, Int_in.kicad_sch, analog_in.kicad_sch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]
2024-09-18 sch: pcb: add a diode for external 5V input to protect USB VBUS
    [supply.kicad_sch]
2024-09-19 fix: qspi ncs port issue, port naming
    [asynthosc.kicad_sch, soc.kicad_sch]
2024-09-19 fix: dividor bridge for usb vbus input sensing
    [asynthosc.kicad_sch, soc.kicad_sch, supply.kicad_sch]
2024-09-19 fix: put all components after fuse
    [soc.kicad_sch, supply.kicad_sch]
2024-09-19 fix: divider bridge stupid mistake
    [soc.kicad_sch, supply.kicad_sch]
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2024-09-19 fix: ldo tab is vout
    [supply.kicad_sch]
2024-09-19 pcb: wip: update from sch fixes
2024-09-24 fix: ethernet stage pull-up resistors
    [ethernet.kicad_sch]
2024-09-24 fix: ethernet filtering capacitor size
    [ethernet.kicad_sch]
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2024-09-24 sch: add decoupling capacitor to 10V switch
    [supply.kicad_sch]
2024-09-24 sch: nc to gnd
    [interface.kicad_sch]
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2024-09-25 sch: modifs on supply
    [supply.kicad_sch]
2024-09-25 bom: adding jlc ref to generic
    [CVin.kicad_sch, Int_in.kicad_sch, analog_in.kicad_sch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]
2024-09-25 bom: update led footprint
    [soc.kicad_sch]
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2024-09-26 bom: update jlcpcb part numbers
    [ethernet.kicad_sch, supply.kicad_sch]
2024-09-27 sch: bom: fix footprints and bom
    [CVin.kicad_sch, Int_in.kicad_sch, analog_in.kicad_sch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]
2024-09-27 fix: footprint: button is polarized, fix led according to easyeda footprint
    [interface.kicad_sch, soc.kicad_sch]
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2024-09-27 sch: decoupling to aop
    [analog_in.kicad_sch]
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2024-09-30 simu: ignore component in simulation
    [analog_in.kicad_sch, ethernet.kicad_sch, interface.kicad_sch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]
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2024-11-04 bom: fab: switch component due to fab shortage
    [CVin.kicad_sch, analog_in.kicad_sch, ethernet.kicad_sch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]
2024-11-11 doc: add rotation file for jlc-kicad-tools
    [cpl_rotations_db.csv]
2024-11-11 cleanup: remove work temp work files
    [bom.csv, bom_stm32.csv]
2024-11-19 panel: add cover panel draft
    [asynthosc_panel.kicad_pcb, asynthosc_panel.kicad_sch]
2025-02-09 doc: fix: bringup notes, phy led2 should be pulled down
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2025-05-02 sch: phy fixes on ldo and leds
    [ethernet.kicad_sch]
2025-05-02 pcb: wip breaking wrong nets
2025-05-02 sch: bump to kicad 9
    [CVin.kicad_sch, Int_in.kicad_sch, analog_in.kicad_sch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]
2025-05-02 sch: update footprint for kicad9
    [soc.kicad_sch]
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2025-05-02 sch: update to k9 libs, fix nets
    [Int_in.kicad_sch, ethernet.kicad_sch, soc.kicad_sch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]
2025-05-02 pcb: current fixes, update to 0.2
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2025-05-02 fix: better dimensions
    [asynthosc_panel.kicad_pcb]
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2026-05-18 lib: invisible pin fix
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2026-05-21 [PANEL] Update front panel (#8)
    With crazy footprints for see-through reverse LEDs
    [asynthosc_panel.kicad_pcb, asynthosc_panel.kicad_sch]
2026-05-28 [DOC] Reverse LED options
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

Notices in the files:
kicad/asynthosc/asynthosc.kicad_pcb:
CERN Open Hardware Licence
